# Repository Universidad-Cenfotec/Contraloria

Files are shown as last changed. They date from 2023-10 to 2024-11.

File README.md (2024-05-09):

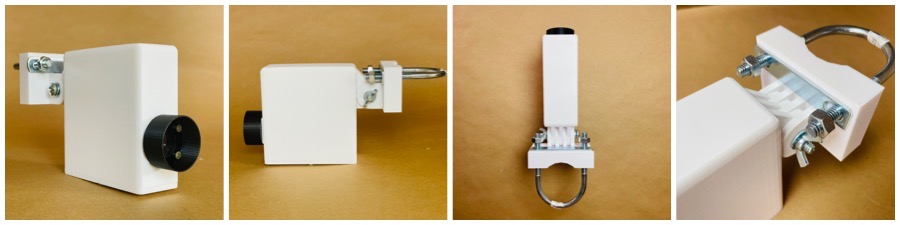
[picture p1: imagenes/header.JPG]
camara IoT

# Proyecto Fiscalización de Obra Pública IoT

Este es el resultado de un proyecto de investigación en coordinación con la Contraloría General de la República de Costa Rica y la cooperación alemana GIZ, para el desarrollo de cámaras IoT de bajo costo, que permitan monitorear y fiscalizar obras de construcción pública, incorporando ideas novedosas para el desarrollo de tecnología local y de bajo costo, además de la utilización de Inteligencia artificial para identificación de patrones de progreso de construcción pública. Este es el repositorio con todos los resultados del proyecto, y que permite su reproducción abierta.

El repositorio del piloto realizado por la contraloría se encuentra en este link:
https://github.com/cgrcostarica/fiscalizacion_infra_IA

## Organización del repositorio
- "code" códigos para los dispositivos utilizados. e instrucciones para programar el microcontrolador
- "design" Archivos 2D y 3D de diseño de estructuras de fabricación y soporte del sistema. Video instruccional de ensamblado de la cámara
- "documentos" Documentación de respaldo (presentaciones, reportes técnicos, documentos de soporte)
- "imagenes" conteien las imágenes que se utilizan en este repositorio
- "placa_tpl" detalles del diseño de la placa TPL, y los esquemas para fabricación

Estes es un proyecto realizado por **Universidad Cenfotec**, en cooperación con la Contraloría General de la República, con fondos de la GIZ.

Aunque exiten tecnologías en el mercado que podría cumplir esta función, este proyecto va dentro de la filosofía "Nuestros para fabricar, adaptar, reparar y crecer", es decir, la intencióne s crear tecnología sobre la cual se pueda evolucionar, y cuyo mejoramiento dependa de nuestras propias acciones y no de la capacidad de un proveedor.

## Investigadores Principales

Dr. Tomás de Camino Beck

Dr. Luis Carlos Naranjo

## Investigadores de apoyo

M.Sc. Rodrigo Herrera

# Asistentes de Investigación y Fabricación

Estudiante Jeffry Valverde

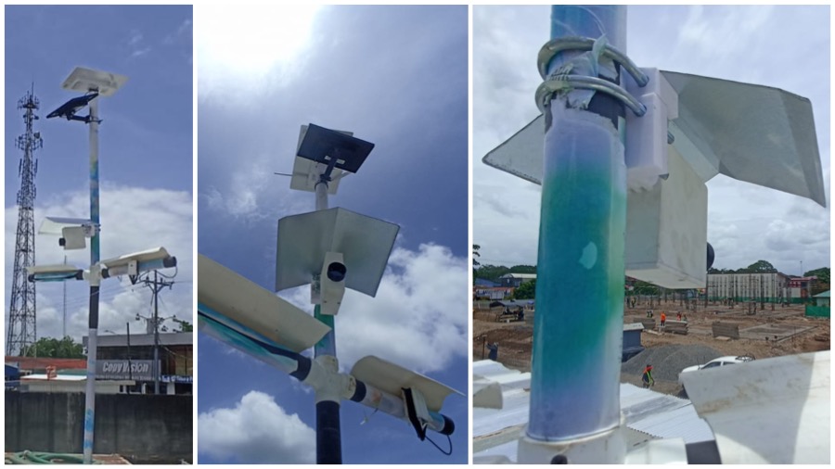
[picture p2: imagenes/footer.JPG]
Camaras Instaladas


# Etapa de Inteligencia Artificial

**Objetivo:** Crear un modelo de inteligencia artificial que permita realizar la detección de objetos en las imagenes captadas en la etapa de IOT relacionadas al proyecto de contrucción de la Escuela de Pocosi. 

## Investigadores Principales
M.Sc. Rodrigo Herrera

## Asistentes de Investigación y Desarrollo
Gabriel Lobo

Dr. Tomás de Camino Beck

La documentación necesaria de la etapa de IA se encuentra en la carpeta "Documentos Etapa IA-GIZ-CENFOTEC", dentro de la misma contiene la siguiente organización.
- "Códigos" :
  - Los archivos del docker que va en el proceso de producción *sin los modelos
  - El proceso de entrenamiento
  - Autenticación de Google Drive
- "Documentación"
  - La documentación necesaria para todos los procesos
- "Imagenes y Etiquetas
  - Etiquetas necesarias para llevar a cabo el proceso de entrenamiento y evaluación
  - Ejemplo de 5 imagenes
- "Modelos"
  - Contiene un txt que indica donde se puede encontrar los modelos
 
## Resultados de Modelos

Se han compartido 1 modelo principal. 
- Modelo_1_29
  - Metricas
    - Promedio de IoU: 82.7%
    - Sensitividad: 85.4% (Equivale a las predicciones verdaderamente predichas)

### Ejemplo de Inferencia 1
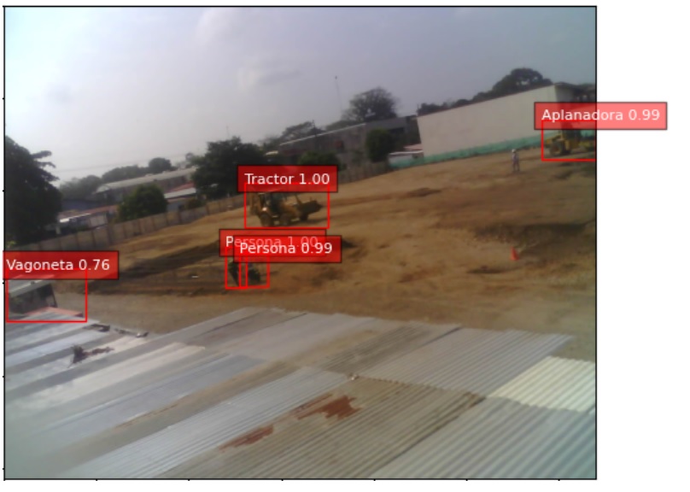
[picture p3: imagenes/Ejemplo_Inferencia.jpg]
Ejemplo de Inferencia
 

### Ejemplo de Inferencia 2
En este ejemplo se puede observar 2 cajas de diferente color en cada objeto. 

- La caja Azul es la caja de la etiqueta real

- La caja Roja es la caja de la predicción realizada por el modelo

Fácilemente se puede apreciar la efectividad del modelo en hacer su trabajo de predicción. 
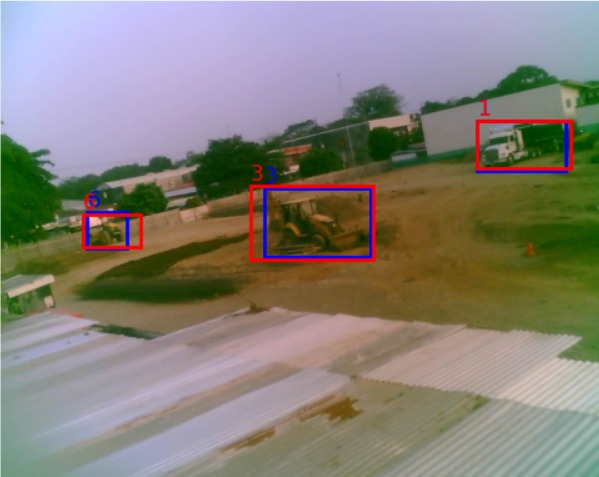
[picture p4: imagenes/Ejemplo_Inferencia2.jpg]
Ejemplo 2 de Inferencia


### Ejemplo de tabla de resultados
Parte del objetivo es analizar las imagenes que se obtengan por día y de estas obtener un archivo CSV en el cual permita analizar los resultados de una forma ágil y obtener resultados de analísis del monitoreo en las obras. 

En la siguiente imagen se observa un ejemplo del archivo CSV creado de las inferencias realizadas por el modelo, el mismo contiene 4 columnas
- Nombre de la Imagen = imagen analizada
- Clase = predicción de los objetos encontrados
- Probabilidad = probabilidad del objeto encontrado
- Recuadro = las coordenadas necesarias de donde se encontro el objeto en la imagen analizada

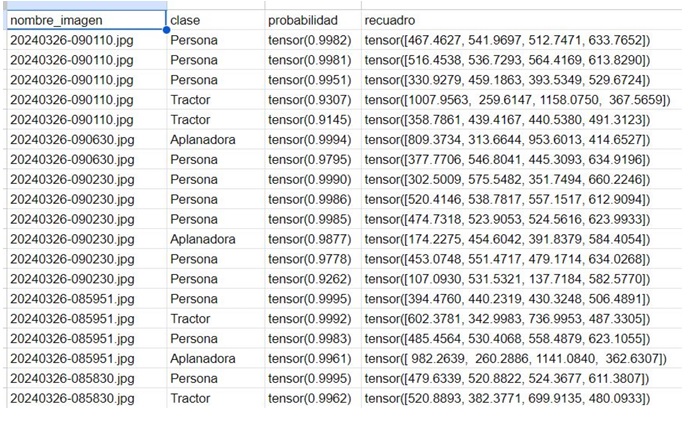
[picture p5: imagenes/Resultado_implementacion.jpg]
Tabla de Resultados


*Se debe tomar en cuenta que este modelo esta entrenado solamente con imagenes captadas por las camaras realizadas en la etapa de IoT para el proyecto de construcción de la Escuela de Pocosí, por ende este modelo esta sobre-entrenado para realizar inferencias para este proyecto, en caso de que se ponga el modelo a realizar inferencias de otras imagenes, o proyectos diferentes, es posible que el modelo no sea lo esperado en su eficiencia.

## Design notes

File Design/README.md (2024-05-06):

# Proceso de Diseño

- El proceso de diseño se explica en el [siguiente video](https://drive.google.com/file/d/1DGaU7ya0ZxTkijEyFO8wcMf-l3KS4jHS/view?usp=sharing)

# Archivos de Diseño

1. Caja_Camara_P1.stl  Caja que contiene la cámara
2. Caja_Camara_P2.stl  Tapa de la caja de cámara
3. Union_Camara_Poste.stl Pieza que sostiene la cámara al poste
4. Visor_Camara.stl Visor que proteje el elnte de lluvia y luz
5. Cubierta_Lente.svg  archivo para corte láser que ptotege el lente del ESP32CAM
6. Anclaje_Techo.stl Pieza que sostiene un techo de zinc al poste

# Recomendaciones para imprimir 3D

- Plástico: PLA MAX
- Pintura exterior esmalte blanco (protección rayos UV)
- Resolución: 0.2mm
- Capas y Paredes: forzar cuatro capas de paredes
- Relleno: 60% con patrón triangular para darle más resistencia
- La impresión tarda aproximadamente 9h25m en una Prusa MK4 en modo impresión rápida

--- 
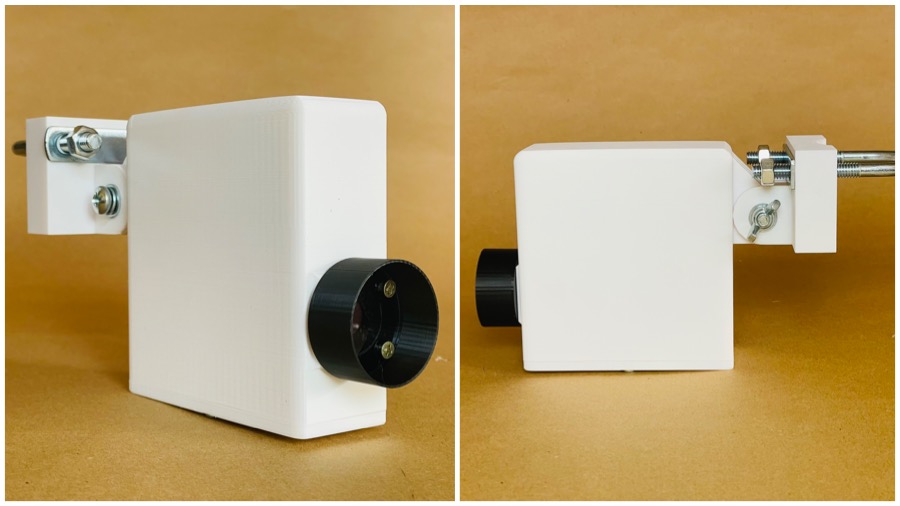
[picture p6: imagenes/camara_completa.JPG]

# Instrucciones de Armado de la Cámara

## Caja de la cámara
- Las instrucciones de armado de la cámara las ueden ver en el [siguiente video](https://drive.google.com/file/d/1R8fjxk--XU2Z1inmcDHXZ_iKdpq5K-TY/view?usp=sharing)
## Incorporar el ESP32 a la caja
- Cambiar el WiFi y direcciónd e Google Drive, siguiendo estas instrucciones
- El ESP32, se conecta a la placa TPL5110, a través de el adaptador de plástico como se muestra en la siguientes fotos
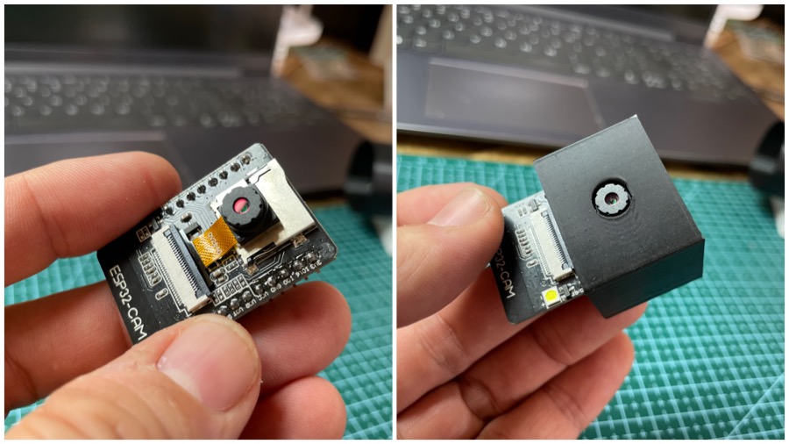
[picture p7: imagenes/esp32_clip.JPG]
ESP32 Clip
  
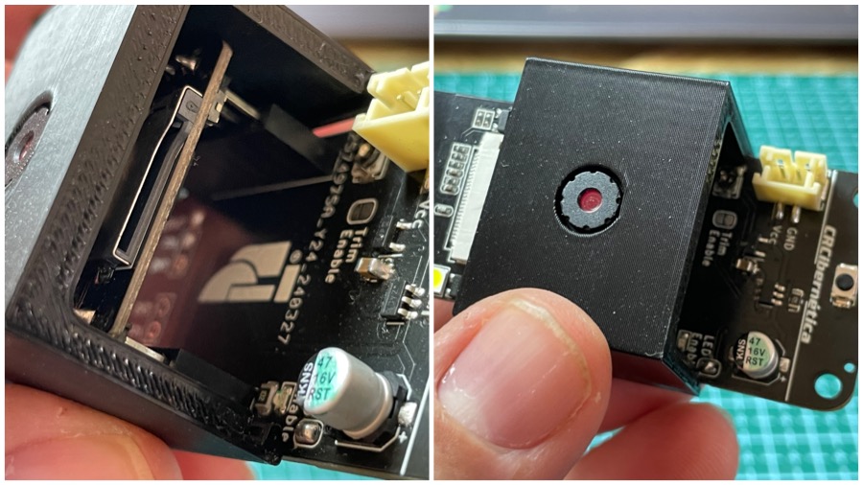
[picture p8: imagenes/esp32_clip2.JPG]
  
- Una vez conectado el ESP32 a la placa, se conectan las baterías, seinserta en la cámara, con cuidado, como se muestra en las siguientes fotografías
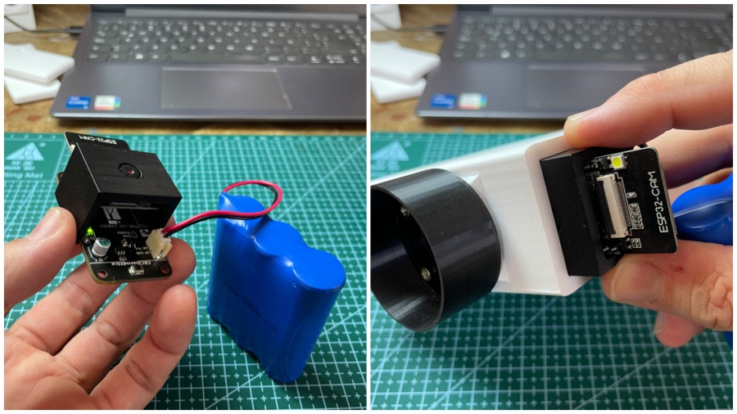
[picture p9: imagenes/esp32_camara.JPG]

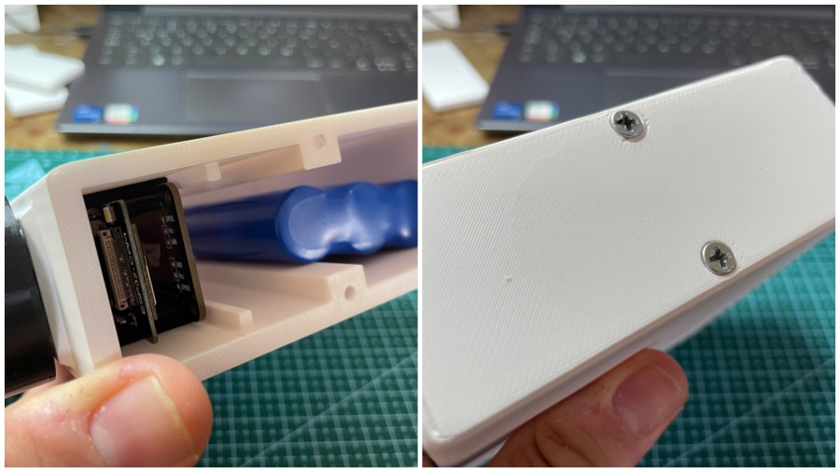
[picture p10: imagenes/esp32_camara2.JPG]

- Una vez cerrada la cámara probar que suba las fotos.

## Modificación de los intervalos de fotografía
- Para modificar en intervalo en que el ESP32 toma las fotos, seguir las instrucciones de este video.

## Cargado de baterías

- Para el cargado de baterías seguir las instrucciones del siguiente video

---
# Historial de Diseño

## Versión 1

Problemas:
- Tapa difícil de colocar
- Cavidad permite pocos tipos de batería
- Se necesita dar vuelta a la imágen
- "Lente" difícil de instalar, y no se puede reparar.
- No resiste golpes muy fuertes

## Versión 2

Problemas:
- Lente expuesto se moja fácilmente
- Acrílico genera reflejos que hace que la foto se sobre exponga
- Union a anclaje hace que cámara quede muy separada del techo

Todo estos problemas han sido corregidos en la verisón final publicada

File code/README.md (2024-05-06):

# Códigos proyecto contraloría

El código ESP32CAM_Timer_CGR_Day.ino proporcionado realiza varias operaciones con un módulo de cámara ESP32CAM, culminando en el envío de una imagen a Google Drive. Una característica notable es el uso de `digitalWrite(donepin, HIGH)`, que se emplea para indicar la finalización de un proceso, activando un temporizador que apaga el controlador. A continuación, se detalla cómo se integra esta función dentro del flujo de trabajo del código:

1. **Establecimiento de la conexión WiFi**:
   - El ESP32 intenta conectarse a la red WiFi especificada. Si no logra conectarse dentro de un número máximo de intentos (`MAX_TRIES`), se considera que ha fallado.
   - Al fallar, ejecuta `digitalWrite(donepin, HIGH)` para indicar que el proceso ha terminado y activa un temporizador externo, que eventualmente apaga el controlador.

2. **Sincronización de tiempo y verificación de horario**:
   - Después de establecer la conexión WiFi, el ESP32 sincroniza su reloj con un servidor NTP.
   - Verifica si la hora actual está fuera del rango establecido (antes de las 5 a.m. o después de las 6 p.m.). Si es así, se activa el temporizador externo mediante `digitalWrite(donepin, HIGH)` para apagar el dispositivo.

3. **Inicialización y configuración de la cámara**:
   - Se configura y activa la cámara. Si la inicialización falla, el sistema se reinicia.
   - Al finalizar la captura y el envío de la imagen, se activa nuevamente el temporizador externo con `digitalWrite(donepin, HIGH)`, indicando que el proceso ha concluido.

4. **Función `saveCapturedImage()`**:
   - Realiza la captura de la imagen, la codificación en base64 y la envía a Google Drive.
   - Tras enviar la imagen, se activa el temporizador externo con `digitalWrite(donepin, HIGH)` para indicar el fin del proceso.

5. **Apagado del sistema**:
   - Cada vez que se llama a `digitalWrite(donepin, HIGH)`, se señala a un circuito externo (probablemente un temporizador o un controlador de potencia) para que inicie el proceso de apagado del ESP32.
  
¡Claro! Aquí tienes un conjunto básico de instrucciones para programar un ESP32-CAM utilizando el Arduino IDE:

---
# Programando el ESP32-CAM

- Para una explicación completa de como cargar el código a el ESP32-CAM, utilizando el Arduino IDE, lo encontrarán en [este video](https://drive.google.com/file/d/1rJqG5vgmPwFNBq3uttZ2uOI0OXYprOTJ/view?usp=sharing).

---
# Cambio de SSID y Password para red MiFi/WiFi

Para cambiar el acceso WiFi en el código proporcionado, sigue estos pasos:

1. **Abre el Código en el Arduino IDE:**
   - Abre el Arduino IDE en tu ordenador.
   - Copia y pega el código proporcionado en este GitHub en una nueva ventana del Arduino IDE.

2. **Edita la Información de la Red:**
   - Reemplaza el SSID y la contraseña con los de tu red WiFi. Por ejemplo:

   ```cpp
   const char* ssid = "nombre_de_tu_red_wifi";
   const char* password = "tu_contraseña_wifi";
   ```

5. **Guarda y Carga el Código:**
   - Guarda los cambios en el código.
   - Conecta tu ESP32-CAM al ordenador.
   - Selecciona el puerto adecuado y la placa ESP32-CAM en el Arduino IDE.
   - Haz clic en el botón "Upload" para cargar el código modificado en tu ESP32-CAM.

---

# Crear acceso para subir fotos a Google Drive

### 1. Crear el Acceso a Google Drive:

#### 1.1. Crear una Carpeta en Google Drive:
   - Abre Google Drive en tu navegador web.
   - Crea una nueva carpeta donde se guardarán las imágenes que envíe tu ESP32-CAM.

#### 1.2. Obtener el ID de la Carpeta:
   - Haz clic derecho en la carpeta que acabas de crear y selecciona "Obtener enlace".
   - Copia el ID de la carpeta de la URL. El ID de la carpeta es la parte de la URL después de `/folders/`.

#### 1.3. Crear un Nuevo Proyecto en Google Apps Script:
   - Visita el [Editor de Google Apps Script](https://script.google.com/) y crea un nuevo proyecto.

#### 1.4. Escribir el Script en Google Apps Script:
   - En el editor de scripts, copia y pega el siguiente código JavaScript:

   ```javascript
   function doPost(e) {
     var folderId = "ID_de_tu_Carpeta_en_Google_Drive";
     var folder = DriveApp.getFolderById(folderId);
     var blob = e.postData.getBlob();
     var file = folder.createFile(blob);
     return ContentService.createTextOutput("Archivo guardado: " + file.getName());
   }
   ```

   - Reemplaza `"ID_de_tu_Carpeta_en_Google_Drive"` con el ID de la carpeta que obtuviste anteriormente.

#### 1.5. Publicar el Script:
   - Haz clic en `Editar` y selecciona `Desplegar como web app`.
   - En la ventana emergente, elige `Quien tiene acceso a la aplicación: Cualquier persona, incluso anónimos`.
   - Haz clic en `Desplegar` y luego en `OK`.
   - Copia el URL que se genera, lo necesitarás más adelante.

### 2. Modificar el Código para tener Acceso:

#### 2.1. Configurar los Datos de Red WiFi:
   - Abre el código en C/C++ de tu ESP32-CAM.
   - Busca la sección "Datos de Red" y cambia los valores de `ssid` y `password` con los de tu red WiFi:

   ```cpp
   //******* Datos de Red ******
   const char* ssid = "nombre_de_tu_red_wifi";       // El SSID de tu red
   const char* password = "tu_contraseña_wifi";  // Tu contraseña de red
   // ***************************
   ```

   - Sustituye `"nombre_de_tu_red_wifi"` y `"tu_contraseña_wifi"` por el nombre de tu red WiFi y tu contraseña respectivamente.

#### 2.2. Configurar el Script de Google Apps Script:
   - Busca la sección donde se define `myDomain` y `myScript`.
   - Reemplaza `myScript` con el URL del script de Google Apps Script que generaste anteriormente.

   ```cpp
   const char* myDomain = "script.google.com";
   String myScript = "/macros/s/TU_ID_EXEC";    // Reemplaza con tu propio URL
   ```

   - Reemplaza `"TU_ID_EXEC"` con el ID de ejecución que obtuviste del URL del script.

--- 

# Ajuste de los intervalos de tiempo

- Los intervalos en los que se toman la fotografías se ajustan físicamente en la placa TPL, regulando el peqieño potenciómetro de la placa TPL, como se muestra en la siguiente foto.
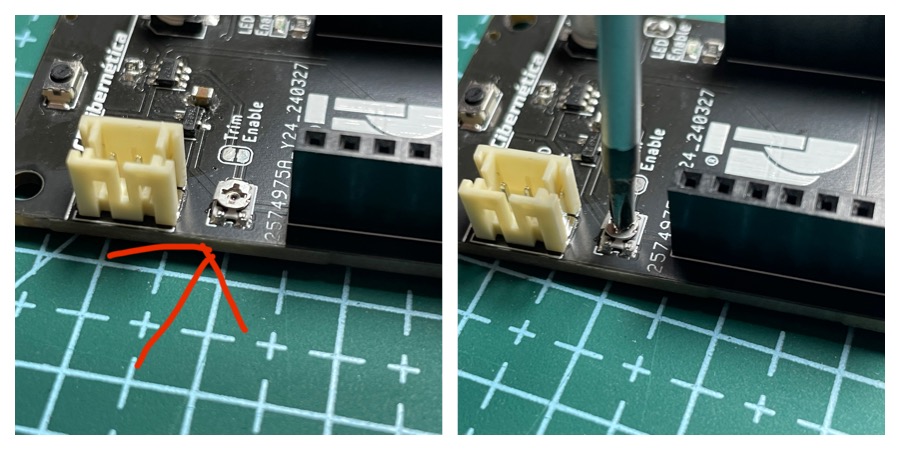
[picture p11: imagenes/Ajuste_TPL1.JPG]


- Cuando el potenciómetro está completamente a la izquierda el intervalo de tiempo es de aproximadamente 2 horas, mientras que cuando está completamente a la derecha, el intervalo es de menos de 1 minuto.  Para efectos del proyecto (intervalo de 10 min), se cooca el potenciómetri alrededor de la 1 del reloj, como se ven en la siguiente foto.

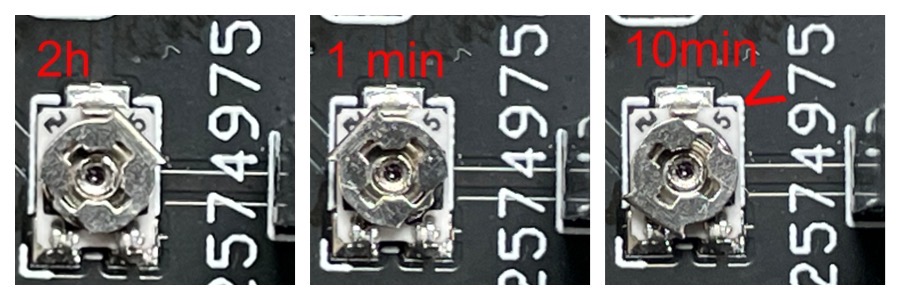
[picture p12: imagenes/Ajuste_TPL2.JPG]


---

# Instrucciones generales de programación de Placa ESP32-CAM

1. **Instalar el Arduino IDE:**
   - Descarga e instala la última versión del Arduino IDE desde el sitio web oficial: https://www.arduino.cc/en/software.

2. **Instalar el Soporte para ESP32 en el Arduino IDE:**
   - Abre el Arduino IDE.
   - Ve a `File (Archivo) > Preferences (Preferencias)`.
   - En el campo "Additional Board Manager URLs (URLs Adicionales del Gestor de Placas)", añade la siguiente URL: `https://dl.espressif.com/dl/package_esp32_index.json`.
   - Haz clic en "OK".
   - Ve a `Tools (Herramientas) > Board (Placa) > Boards Manager (Gestor de Placas)`.
   - Busca "esp32" y pulsa en "Install (Instalar)" para instalar el soporte para ESP32.

3. **Seleccionar la Placa ESP32-CAM:**
   - Ve a `Tools (Herramientas) > Board (Placa)` y selecciona `ESP32 Wrover Module`.

4. **Configurar las Opciones de la Placa:**
   - Ve a `Tools (Herramientas)` y ajusta las siguientes opciones según sea necesario:
     - `Upload Speed (Velocidad de Subida)`: 115200 baudios (o la velocidad de subida que mejor funcione para tu configuración).
     - `Flash Frequency (Frecuencia de Flash)`: 40 MHz.
     - `Flash Mode (Modo de Flash)`: QIO.
     - `Partition Scheme (Esquema de Partición)`: Huge APP (3MB No OTA/1MB SPIFFS).

5. **Conectar el ESP32-CAM a tu Ordenador:**
   - Conecta tu ESP32-CAM al ordenador utilizando un cable micro-USB.

6. **Configurar el Arduino IDE para la Comunicación con el ESP32-CAM:**
   - Si es la primera vez que utilizas el ESP32-CAM con tu ordenador, es posible que necesites instalar los controladores correspondientes. En la mayoría de los casos, el sistema operativo los instalará automáticamente, pero si experimentas problemas de comunicación, puedes buscar los controladores en línea.

7. **Cargar un Ejemplo o Escribir Tu Propio Código:**
   - Ve a `File (Archivo) > Examples (Ejemplos)` y selecciona un ejemplo para comenzar, como `CameraWebServer` o `CameraWebServer.ino`.
   - O bien, escribe tu propio código en el Arduino IDE.

8. **Modificar el Código (si es necesario):**
   - Si estás utilizando un ejemplo, puedes necesitar modificar ciertas partes del código, como la configuración del Wi-Fi (SSID y contraseña) para que coincida con tu red Wi-Fi.

9. **Compilar y Subir el Código:**
   - Haz clic en el botón "Upload (Subir)" en la esquina superior izquierda del Arduino IDE.
   - Espera a que el código se compile y se suba al ESP32-CAM.

10. **Verificar la Ejecución:**
    - Una vez que la carga haya finalizado correctamente, abre el Monitor Serie (`Tools (Herramientas) > Serial Monitor (Monitor Serie)`) para ver la salida del ESP32-CAM.
    - Si has cargado un ejemplo de cámara web, deberías poder acceder a la dirección IP del ESP32-CAM desde un navegador web y ver la transmisión de la cámara.

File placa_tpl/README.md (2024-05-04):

# Placa TPL para ESP32CAM

Shield para cámara ESP32CAM, con chip TPL para fotos a intervalos y bajo consumo de batería. Diseñado por Tomás de Camino Beck, con ayuda de CrCibernetica.com, para poryecto GIZ-CGR-Universidad Cenfotec.

Para actualizciones de esta placa puede revisar [este repositorio](https://github.com/CRCibernetica/cnft-tpl-esp32cam)

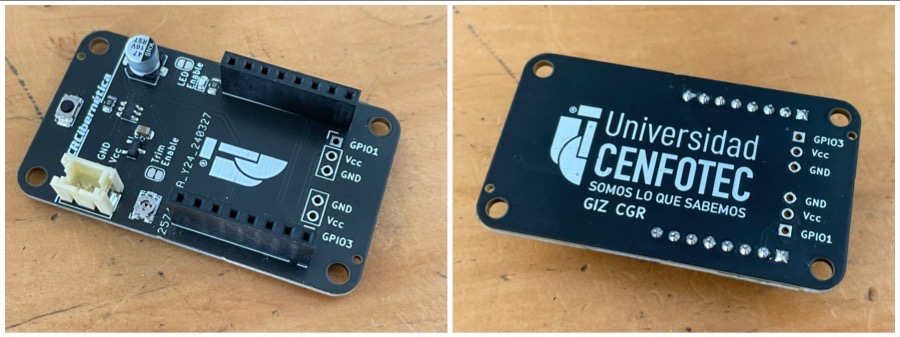
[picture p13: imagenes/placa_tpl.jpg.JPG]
Placa TPL


# Prototipado de la placa

La placa se desarrolla a partir del chip TPL5110.  En la fotografía se muestra 1. Pruebas breadboard, 2. fabricado protoboard, 3. placa final fabricada en china

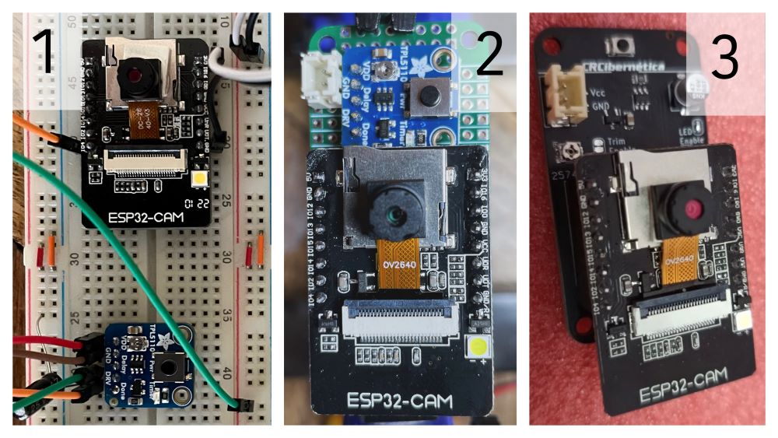
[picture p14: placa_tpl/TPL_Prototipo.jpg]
prototipado


# Breadboard

Utilizando el TPL5110 de Adafruir puede construir el circuito en un breadboard siguiendo el siguiente esquema:
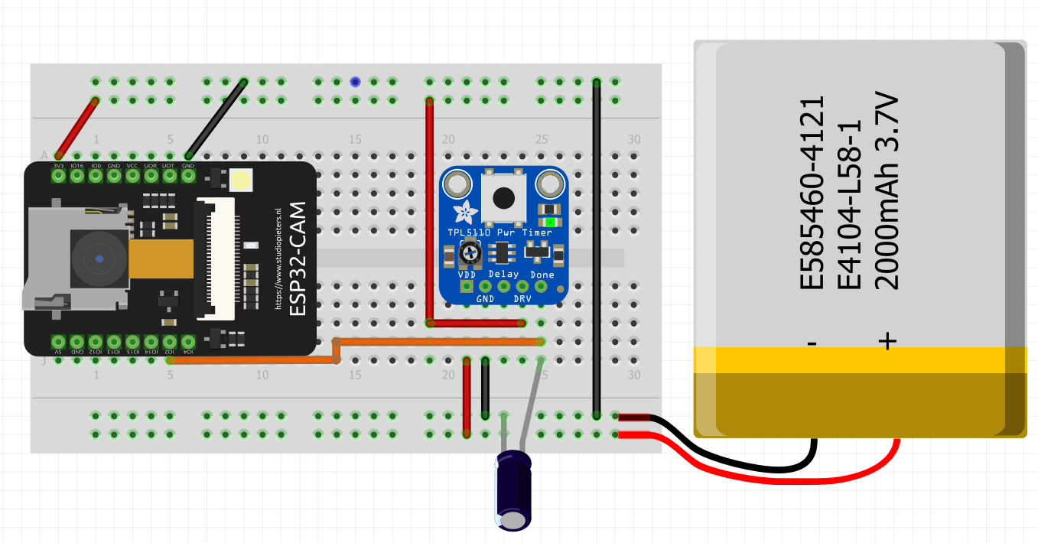
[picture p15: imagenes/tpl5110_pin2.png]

Nota: El capacitor puede variar depediendo de la batería que se utilice. Para este proyecto se utilizó 47uF 16v

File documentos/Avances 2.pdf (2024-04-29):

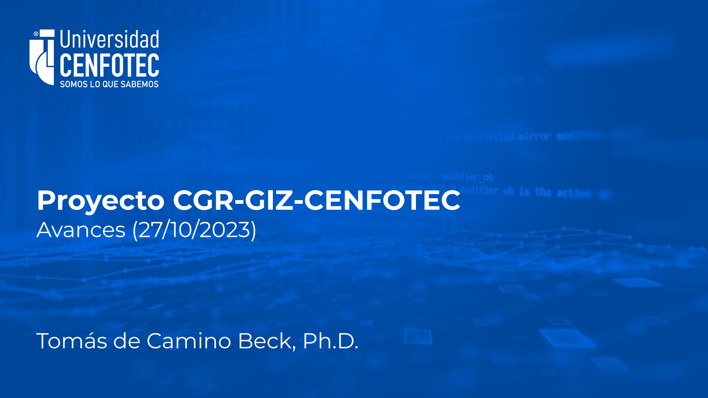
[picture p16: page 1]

Tomás de Camino Beck, Ph.D.

# Proyecto CGR-GIZ-CENFOTEC

# Avances (27/10/2023)

# CGR-GIZ-CENFOTEC

# Energía

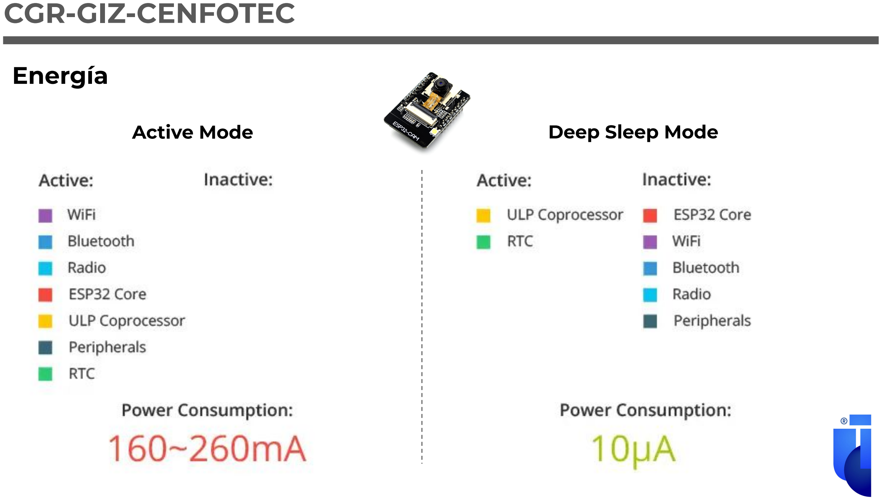
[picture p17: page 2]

Active Mode | Deep Sleep Mode

# CGR-GIZ-CENFOTEC

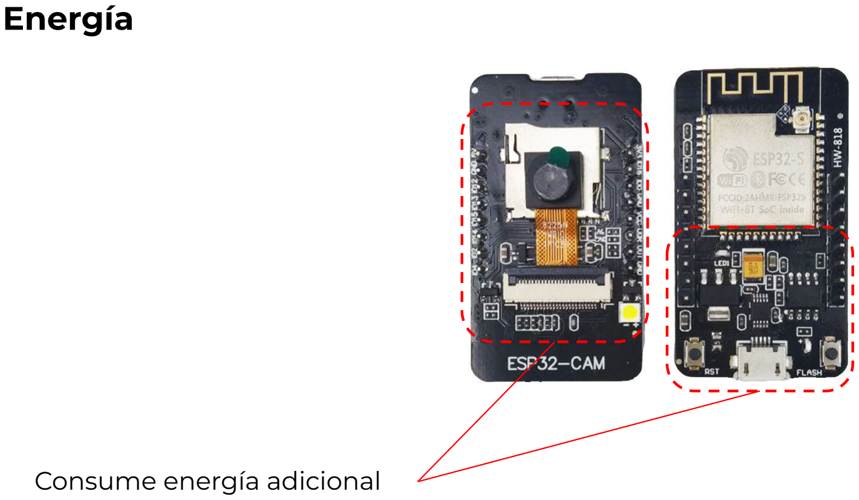
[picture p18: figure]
Energía; Consume energía adicional

# CGR-GIZ-CENFOTEC

# Energía

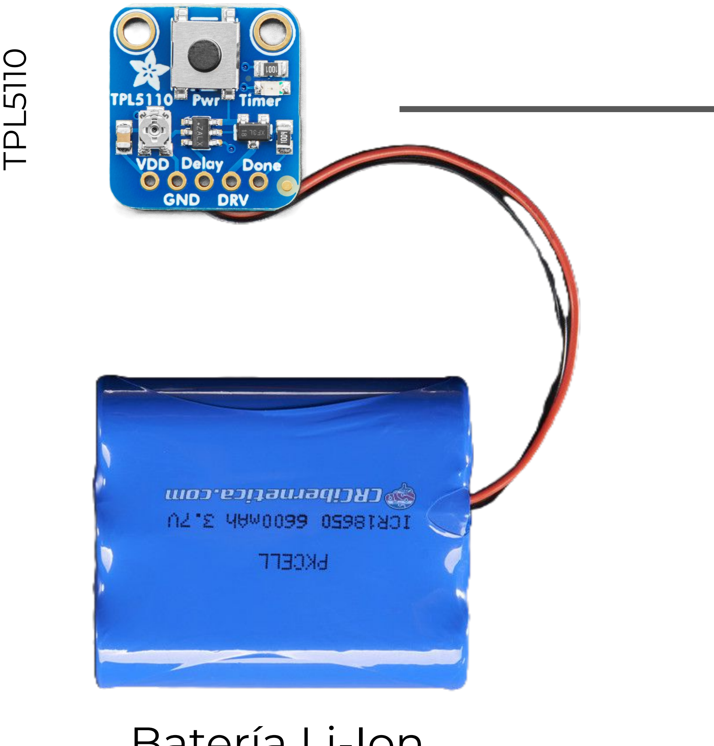
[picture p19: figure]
TPL5110

# Batería Li-Ion

3.7 V

## 66000mAh

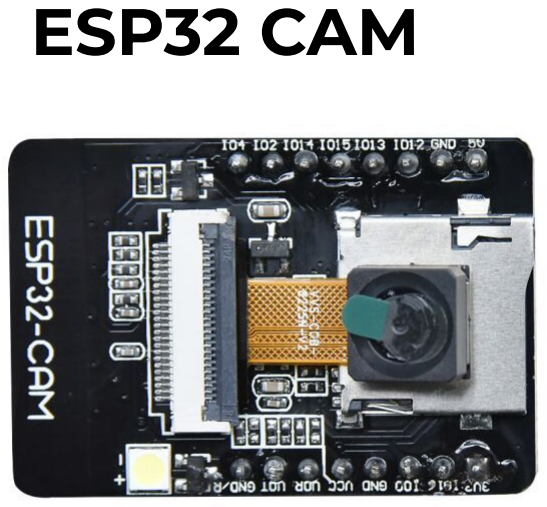
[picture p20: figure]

# ESP32 CAM Timer (externo)

# CGR-GIZ-CENFOTEC

# Energía

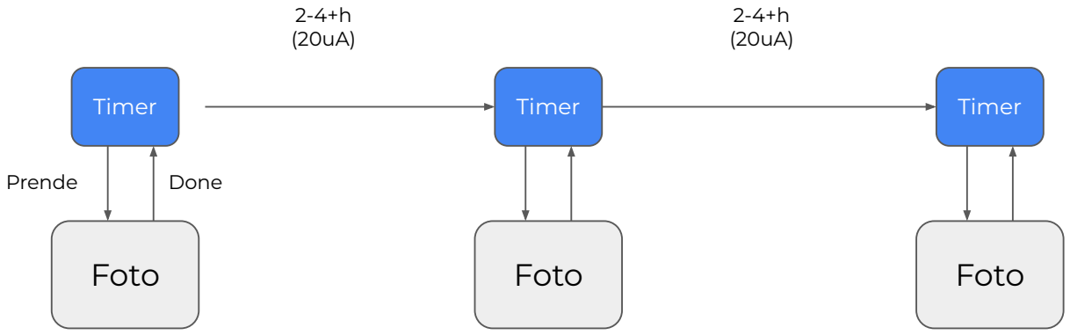
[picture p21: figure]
Foto; Timer; Prende; Done

5-10 s
(260mA)

5-10 s
(260mA)

5-10 s
(260mA)

# CGR-GIZ-CENFOTEC

# Ventajas - Simplifica el diseño - No requiere paneles solares - Dura más de 1 año con batería - Facilita protección a exteriores - Minimiza consumo energía - Garantiza lectura regular - Maximiza vida útil del controlador

# CGR-GIZ-CENFOTEC

# Caja

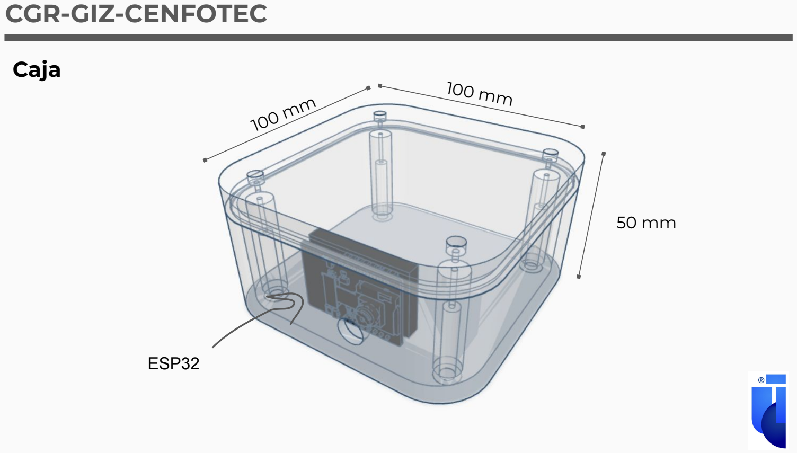
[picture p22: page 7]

# ESP32

50 mm

100 mm
100 mm

# CGR-GIZ-CENFOTEC

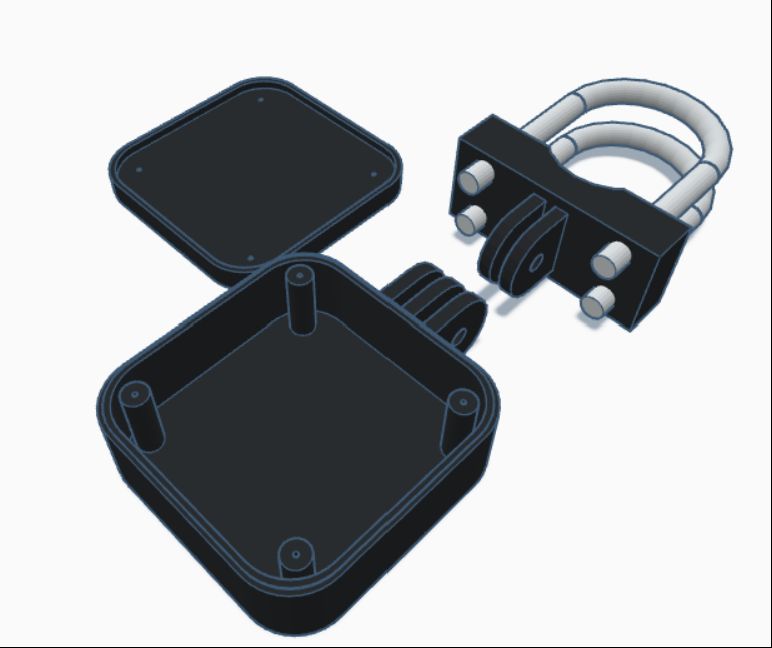
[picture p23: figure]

# Soporte

# CGR-GIZ-CENFOTEC

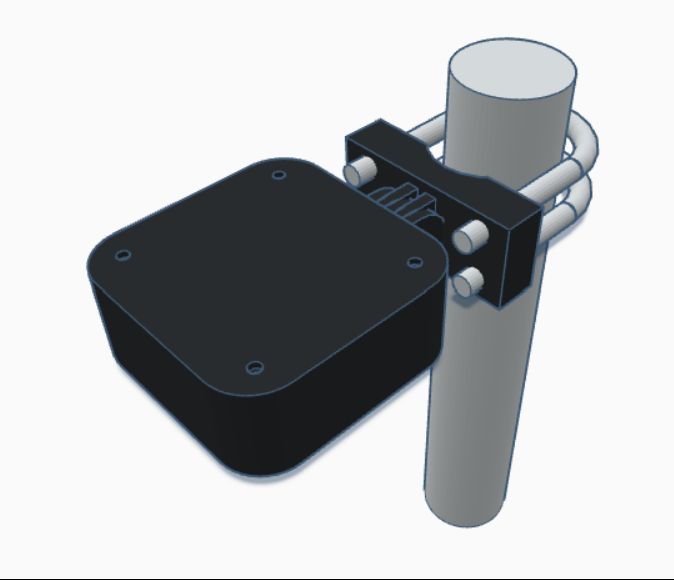
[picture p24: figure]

# Soporte

# CGR-GIZ-CENFOTEC

# Soporte

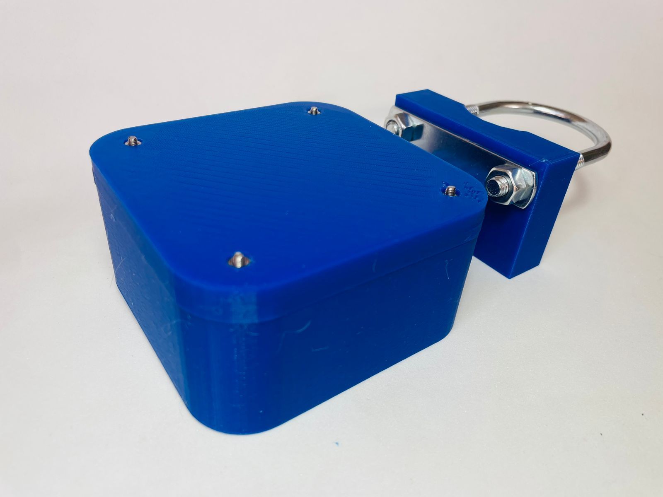
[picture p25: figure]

# CGR-GIZ-CENFOTEC

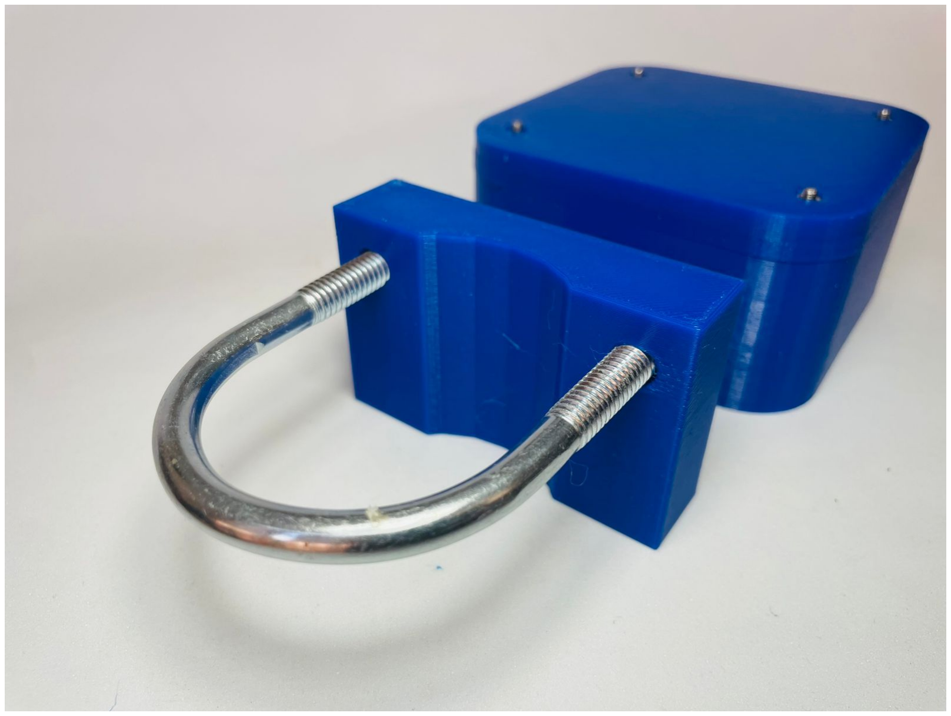
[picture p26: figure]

# Soporte

# CGR-GIZ-CENFOTEC

# Soporte

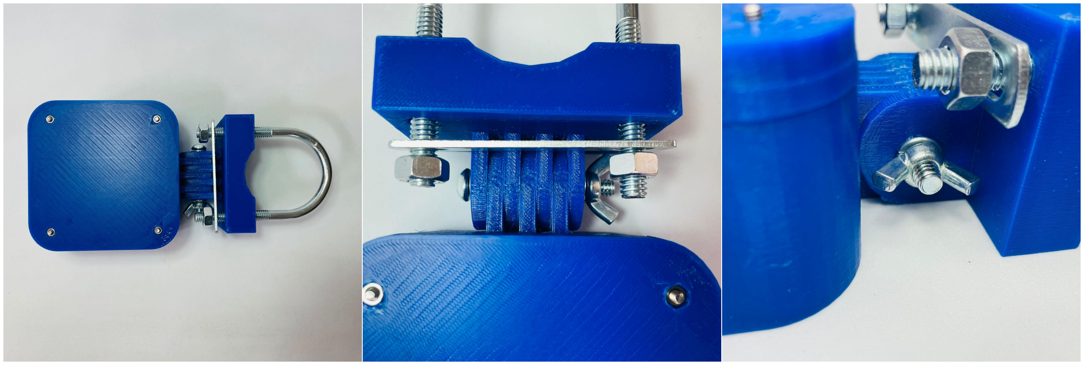
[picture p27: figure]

# CGR-GIZ-CENFOTEC

# Soporte

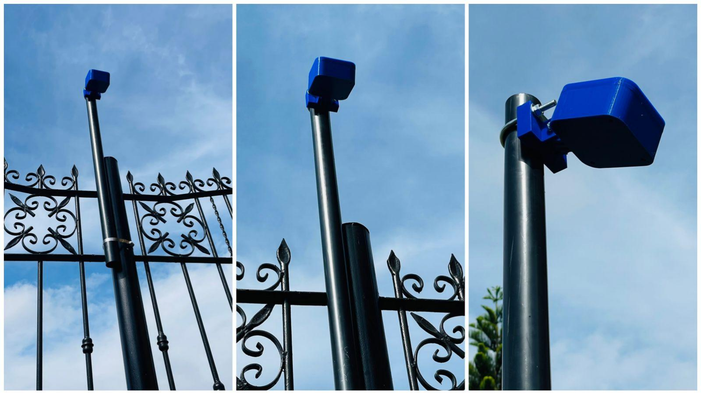
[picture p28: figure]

# CGR-GIZ-CENFOTEC

Item | Descripción | Resultados Preliminares | Estado
Pruebas de microcontroladores | Pruebas de diferentes microcontroladores | Se probaron Arduino Nicla, T-Camera, ESP32 CAM, Se determina que ESP32 es la mejor opción | Listo
| | evitar su uso | Listo
| Baterías | Li-Ion 6600mAh, LiPo 5500mAh, LiPo 2500mAh, CR123 Li | Listo
| Estados de baja energía | Deep Sleep, Aumenta duración de batería. PLacas traen muchos componentes que gastan energía, PLaca en prueba (lleva 1 semana) | Listo
| Timer | En Proceso | En Proceso
Pruebas de Energía | Paneles solares | Se probó voltaic, no se descarta, pero se trata de
Caja | Diseño | DIseño simple | Listo
Impresión 3D | Diseño trabajable en Tinkedcad | Listo
Materiales | ASA, PLA | Listo
Resistencia | Pruebas en exterior en Proceso | En Proceso

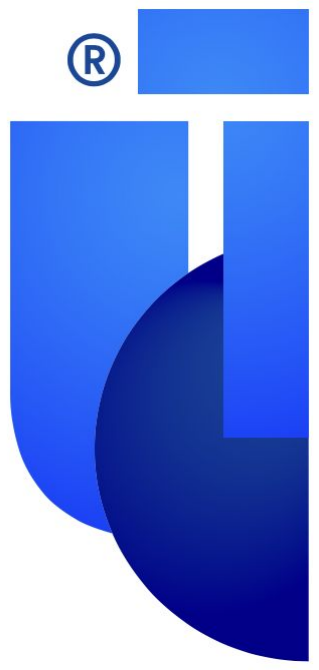
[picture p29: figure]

# @tomasdecamino

# tdecamino@ucenfotec.ac.cr

# ¿Preguntas?

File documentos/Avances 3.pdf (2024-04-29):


Tomás de Camino Beck, Ph.D.

## Proyecto CGR-GIZ-CENFOTEC

Avances (23/11/2023)

Concepto; Internet; Soporte; Cámara; Caja; Energía

CGR-GIZ-CENFOTEC

CGR-GIZ-CENFOTEC

Principios de Diseño

- Duradero (no eterno)
- Bajo Costo
- Reparable
- Replicable
- Modificable
- Energéticamente independiente (evitar paneles solares)
- Fácil de instalar
- Código y diseños abiertos (Open Source)


CGR-GIZ-CENFOTEC

Soporte

CGR-GIZ-CENFOTEC


Soporte

CGR-GIZ-CENFOTEC

Soporte


CGR-GIZ-CENFOTEC


Soporte

CGR-GIZ-CENFOTEC


Circuito

CGR-GIZ-CENFOTEC


Circuito

CGR-GIZ-CENFOTEC


Circuito

CGR-GIZ-CENFOTEC

Circuito


CGR-GIZ-CENFOTEC


Ensamblado


CGR-GIZ-CENFOTEC

Ensamblado

CGR-GIZ-CENFOTEC

Ensamblado


CGR-GIZ-CENFOTEC

Funcionamiento

Fotografía; (reconocimiento patrones); Decisión; Juicio

CGR-GIZ-CENFOTEC


IA


@tomasdecamino

tdecamino@ucenfotec.ac.cr

# ¿Preguntas?

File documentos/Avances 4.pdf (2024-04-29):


Tomás de Camino Beck, Ph.D.

## Proyecto CGR-GIZ-CENFOTEC

Avances (8/03/2024)

CGR-GIZ-CENFOTEC


CGR-GIZ-CENFOTEC

Versión 1 | Versión 2

CGR-GIZ-CENFOTEC


CGR-GIZ-CENFOTEC


CGR-GIZ-CENFOTEC


CGR-GIZ-CENFOTEC


CGR-GIZ-CENFOTEC

Circuito

Pruebas con pin 4,2,16 Pruebas con Capacitores

Pruebas SD

Pruebas
Baterías


CGR-GIZ-CENFOTEC

CGR-GIZ-CENFOTEC


CGR-GIZ-CENFOTEC


CGR-GIZ-CENFOTEC


CGR-GIZ-CENFOTEC

Importante

- Revisión de electrónica
- Diseño de placa (CrCibernetica)
- Pruebas de caja (se rediseño)
- Diseño de techo
- Fabricación de cámara (12h)
- Cambio de batería
- Algunos asuntos del código
- DIstancia de sitio de prueba (Pococí está muy largo)
- Semana Santa


@tomasdecamino

tdecamino@ucenfotec.ac.cr

# ¿Preguntas?

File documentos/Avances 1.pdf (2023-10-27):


Tomás de Camino Beck, Ph.D.

# Proyecto CGR-GIZ-CENFOTEC

# Avances (27/10/2023)

# CGR-GIZ-CENFOTEC

# Concepto

Internet; Soporte; Cámara; Caja; Energía

# CGR-GIZ-CENFOTEC

# Supuestos

# (iniciales)

# - Internet: Hay disponibilidad de Wi-Fi. Inicialmente al ser obras MEP, se asume que es posible (MiFi)

# - Energía: Sistema autónomo con energía solar

# - Soporte: Construcción con containers o estructuras de bodega o cercado

# - Cámara: hay visibilidad (fase de preparación de terreno y preparación de fundamentos)

# - Caja: resiste intemperie al menos 1 año

# CGR-GIZ-CENFOTEC

# Internet


# CGR-GIZ-CENFOTEC

# Cámara


ESP32 CAM | NIcla Vision | T-Camera
micro ESP32 soporta IA local | micros soportan IA local | micro ESP32 soporta IA local
Gran cantidad de material en línea | Poca cantidad de material en línea | Gran cantidad de material en línea
$15 | $115 | $50
Cámara 2MP | Cámara 2MP, micrófono, acelerómetro | Cámara 5MP, sensor PIR, pantalla
Modo bajo consumo | ND | Modo bajo consumo
Escalable | ? | ?

# CGR-GIZ-CENFOTEC

# Energía


Active Mode | Deep Sleep Mode

# CGR-GIZ-CENFOTEC

frecuencia de funcionamiento ● Nos interesa que dure meses o semanas ● Carga continua con panel solar; Panel Solar; Super Capacitor; Manejo de Carga; Batería LiPo; ESP32 CAM

Energía | ● | ESP32 puede durar años funcionando, dependiendo de

# Caja

# CGR-GIZ-CENFOTEC


$29

# CGR-GIZ-CENFOTEC

# Caja


### ESP32

50 mm

100 mm
100 mm


# Caja

# CGR-GIZ-CENFOTEC

# Caja

# CGR-GIZ-CENFOTEC


# Sistema

# CGR-GIZ-CENFOTEC


# CGR-GIZ-CENFOTEC

# Sistema


# CGR-GIZ-CENFOTEC

# Sistema


# CGR-GIZ-CENFOTEC


# Soporte

# CGR-GIZ-CENFOTEC


# Soporte

# CGR-GIZ-CENFOTEC

# Soporte



## @tomasdecamino

# tdecamino@ucenfotec.ac.cr

# ¿Preguntas?

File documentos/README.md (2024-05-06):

# Documentación Adicional

- Presetaciones de avance realizadas durante el desarrollo del proyecto.

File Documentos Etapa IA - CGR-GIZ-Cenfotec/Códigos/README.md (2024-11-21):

El modelo completo puede ser sercargao en el siguiente [link](https://drive.google.com/drive/folders/1GQ3o4Iqyp_PoVP5M7APWEdD5sbGEHZOf)

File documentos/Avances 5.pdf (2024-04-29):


Tomás de Camino Beck, Ph.D.

## Proyecto CGR-GIZ-CENFOTEC

Avances (15/03/2024)

CGR-GIZ-CENFOTEC


CGR-GIZ-CENFOTEC


CGR-GIZ-CENFOTEC


CGR-GIZ-CENFOTEC


CGR-GIZ-CENFOTEC

CGR-GIZ-CENFOTEC

CGR-GIZ-CENFOTEC


CGR-GIZ-CENFOTEC


CGR-GIZ-CENFOTEC


CGR-GIZ-CENFOTEC

CGR-GIZ-CENFOTEC


CGR-GIZ-CENFOTEC


CGR-GIZ-CENFOTEC

Importante

- Revisión de electrónica
- Diseño de placa (CrCibernetica)
- Pruebas de caja (se rediseño)
- Diseño de techo
- Fabricación de cámara (12h)
- Cambio de batería
- Algunos asuntos del código

7.5h


@tomasdecamino

tdecamino@ucenfotec.ac.cr

# ¿Preguntas?

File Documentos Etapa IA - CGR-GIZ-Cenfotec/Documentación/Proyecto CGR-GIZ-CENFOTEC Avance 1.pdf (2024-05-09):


# Proyecto CGR-GIZ-CENFOTEC

## IA – Modelo y Estimación de implementación

Msc. Rodrigo Herrera

# CGR-GIZ-CENFOTEC

## Objetivo

## - Avances del Modelo - Demo - Revisión de arquitectura de implementación - Revisión de costos de arquitectura


Imágenes | Vagonetas

Excavadoras


Imágenes
Cargadores

Personas

Imágenes


Cantidad por clase son:

- Dump_truck: 7855
- Excavator: 7323
- Loader: 4870
- Mixer_truck: 1992
- Person: 2192

Mezcladoras


Modelos

Modelo



Modelo


Demo


Arquitectura de implementación

Nuevas Imágenes

Imágenes procesadas

Archivos


Estimación de Costos

# Proyecto CGR-GIZ-CENFOTEC

## IA – Modelo y Estimación de implementación

Msc. Rodrigo Herrera

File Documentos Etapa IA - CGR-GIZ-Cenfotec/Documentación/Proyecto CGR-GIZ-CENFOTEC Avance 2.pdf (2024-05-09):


# Proyecto CGR-GIZ-CENFOTEC

## IA – Modelo y Estimación de implementación

Msc. Rodrigo Herrera

# CGR-GIZ-CENFOTEC

## Objetivo

## - Avances del Modelo - Demo - Revisión de arquitectura de implementación - Revisión de costos de arquitectura


Imágenes | Vagonetas

Excavadoras


Imágenes
Cargadores

Personas

Imágenes


Cantidad por clase son:

- Dump_truck: 7855
- Excavator: 7323
- Loader: 4870
- Mixer_truck: 1992
- Person: 2192

Mezcladoras

Modelos y proceso de entrenamiento



Demo


Arquitectura de implementación

Nuevas Imágenes

Imágenes procesadas


Archivos


Estimación de Costos

# Proyecto CGR-GIZ-CENFOTEC

## IA – Modelo y Estimación de implementación

Msc. Rodrigo Herrera

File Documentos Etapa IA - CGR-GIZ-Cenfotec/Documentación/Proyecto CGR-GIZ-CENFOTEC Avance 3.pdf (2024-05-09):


# Proyecto CGR-GIZ-CENFOTEC

## IA – Modelo y Estimación de implementación

Msc. Rodrigo Herrera

# CGR-GIZ-CENFOTEC

## Objetivo

## - Avances del Modelo - Demo - Revisión de arquitectura de implementación - Revisión de costos de arquitectura


Imágenes | Vagonetas

Excavadoras


Imágenes
Cargadores

Personas

Imágenes


Cantidad por clase son:

- Dump_truck: 7855
- Excavator: 7323
- Loader: 4870
- Mixer_truck: 1992
- Person: 2192

Mezcladoras

Modelos y proceso de entrenamiento


Demo

https://colab.research.google.com/drive/1PjbNF5KaKsJHKqpBVtwylxMjkuDdpaJe?authuser=1#scrollTo=SFEK8fuxPyo7


Resultado del modelo con las imágenes tomadas


Resultado del modelo con las imágenes tomadas


Arquitectura de implementación pensada originalmente

Nuevas Imágenes

Imágenes procesadas


Archivos


Estimación de Costos

# CGR-GIZ-CENFOTEC - Propuesta nueva arquitectura

AWS Cloud; Folder Diario; Archivos Amazon Elastic Container; Registry (Amazon ECR); Image; AWS Lambda; Lambda function; Amazon EventBridge; Rule; Amazon Elastic Container Registry (Amazon ECR); Amazon API Gateway; Endpoint

# CGR-GIZ-CENFOTEC - Costos Nueva arquitectura


Estimación de Costos

# Proyecto CGR-GIZ-CENFOTEC

## IA – Modelo y Estimación de implementación

Msc. Rodrigo Herrera

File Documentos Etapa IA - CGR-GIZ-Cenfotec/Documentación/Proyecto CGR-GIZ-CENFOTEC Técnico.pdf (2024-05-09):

## Proyecto CGR-GIZ-CENFOTEC Etapa - IA

Msc. Rodrigo Herrera

## CGR-GIZ-CENFOTEC

Objetivo

- Explicación técnica de etapa de Inteligencia Artificial Aplicada en detección de Objetos para monitoreo de las construcciones

Agenda

- Imágenes
- Proceso de Etiquetado
- Proceso de Entrenamiento del modelo
- Resultados del modelo
- Arquitectura de Implementación
- Configuraciones
- Resultados de la arquitectura


- Imágenes

- Proceso de Etiquetado


- Se etiquetan un total de
2,121 imágenes
- Se obtiene la siguiente
cantidad de etiquetas por
clase
- 751 Aplanadora
- 1,490 Persona
- 535 Tractor
- 445 Vagoneta
- 25 Mezcladora


- Proceso de Entrenamiento del modelo

Faster R-CNN

- Mayor efectividad en el proceso de

inferencia

- Resultados del modelo


- Resultados del modelo

Promedio de IoU: 82.7%
Recall: 85.4% (Verdaderos positivos)

Azul es la etiqueta y segmentación Rojo es la predicción

AWS Cloud; AWS Lambda; Lambda function; Amazon EventBridge; Rule; Amazon Elastic Container Registry (Amazon ECR); Image; Amazon S3

Folder Diario

Archivos

- Arquitectura de Implementación

- Configuración


- Resultados de la arquitectura


## Proyecto CGR-GIZ-CENFOTEC Etapa - IA

Msc. Rodrigo Herrera

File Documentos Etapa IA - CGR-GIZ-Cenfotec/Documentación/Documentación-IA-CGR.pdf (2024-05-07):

# Documentación del Sistema de Detección de Maquinaria en Obras de Construcción para la CGR

Bienvenid@ a la documentación del sistema de detección de maquinaria en obras de construcción para la Contraloría General de la República. En esta documentación encontrarás información detallada sobre la arquitectura del modelo de detección de objetos, la arquitectura del sistema dentro de AWS y la arquitectura de la imagen de Docker.

## Índice

Arquitectura del Modelo

Proceso de Entrenamiento

Configuración del Sistema en AWS

Configuración de Google Drive API

Estructura del Docker

# Arquitectura del Modelo

El modelo de detección de objetos en imágenes de maquinaria en obras de construcción se basa en FasterRCNN con ResNet50 como red base. FasterRCNN es un modelo de detección de objetos que consta de dos subredes: una red base y una red de detección. La red base es una red convolucional que se encarga de extraer características de la imagen de entrada, mientras que la red de detección es una red que se encarga de realizar la detección de objetos en la imagen.

ResNet50 es una red convolucional profunda que consta de 50 capas. Esta red es utilizada como red base en el modelo, ya que ha demostrado ser efectiva en la extracción de características de imágenes. FasterRCNN con ResNet50 como red base es un modelo de detección de objetos que ha demostrado ser efectivo en la detección de objetos en imágenes de maquinaria en obras de construcción.

La razón principal por la que se eligió ResNet50 como red base es porque es una red profunda que ha sido pre-entrenada en un gran conjunto de datos de imágenes. Esto significa que la red base ya ha aprendido a extraer características de alto nivel de las imágenes, lo que permite detectar objetos en las imágenes con alta precisión. Además, ResNet50 es una red profunda que ha demostrado ser efectiva en la extracción de características de imágenes, lo que la hace ideal para su uso como red base en el modelo de detección de objetos. Comparado con otros modelos, ResNet50 es más rápido y preciso en la detección de objetos en imágenes de maquinaria en obras de construcción.

El modelo de detección de objetos consta de las siguientes etapas:

1. Extracción de características: La red base (ResNet50) se encarga de extraer características de la imagen de entrada. La red base es una red convolucional profunda que ha sido pre-entrenada en un gran conjunto de datos de imágenes. Esta red es capaz de extraer características de alto nivel de la imagen de entrada, lo que permite detectar

objetos en la imagen.

2. Propuestas de regiones: Se generan propuestas de regiones en la imagen que pueden contener objetos. Estas propuestas se generan utilizando una red de detección que se entrena para predecir las regiones en las que es más probable que se encuentren objetos.
3. Extracción de características de las regiones propuestas: Se extraen características de las regiones propuestas utilizando la red base. Estas características se utilizan para clasificar las regiones propuestas en las diferentes clases de objetos.
4. Clasificación de las regiones propuestas: Se clasifican las regiones propuestas en las diferentes clases de objetos. Para ello, se utiliza un clasificador que se entrena para predecir la clase de objeto presente en cada región propuesta.
5. Predicción de las cajas delimitadoras de los objetos: Se predicen las cajas delimitadoras de los objetos en las regiones propuestas. Estas cajas delimitadoras se utilizan para localizar los objetos en la imagen y dibujar las cajas delimitadoras alrededor de los objetos detectados.

La ejemplificación de la arquitectura del modelo se muestra en la siguiente figura:


Una arquitectura como esta permite detectar y clasificar objetos en imágenes con alta precisión y rapidez, dando resultados similares a los que se observan en la siguiente imagen:


En nuestro caso, el modelo fue entrenado con imágenes que poseían uno o varios objetos representados pertenecientes a las siguentes clases o labels:

dump_truck

person

excavator

loader

mixer_truck

steamroller

Volver al inicio

# Proceso de Entrenamiento

Para el proceso de entrenamiento de un modelo de detección de objetos basado en Faster R-CNN con ResNet-50, se utilizó PyTorch y torchvision. A continuación, se detalla la arquitectura y el flujo de trabajo para el entrenamiento, evaluación y visualización de los resultados.

### Documentación del Código de Entrenamiento

Este código implementa un modelo de detección de objetos utilizando PyTorch y el modelo pre-entrenado Faster R-CNN basado en ResNet-50.

import torch
import torchvision
from torchvision.models.detection import fasterrcnn_resnet50_fpn, FasterRCNN_ResNet50_FPN_Weights
from torchvision.models.detection.faster_rcnn import FastRCNNPredictor from torchvision.transforms import functional as F
from torch.utils.data import Dataset, DataLoader
from torch.cuda.amp import GradScaler, autocast
from PIL import Image
import os
import json
import torchvision.transforms as transforms

os.environ['PYTORCH_CUDA_ALLOC_CONF'] = 'max_split_size_mb:128' os.environ['PYTORCH_CUDA_ALLOC_CONF'] = 'expandable_segments:True'

annotations_file = 'path/Train_dataset.json'

def class_text_to_int(class_text):

class_mapping = { "dump_truck": 1,"person": 2,"excavator": 3,"loader": 4,"mixer_truck": 5,"steamroller": 6}
return class_mapping.get(class_text, None)

class CustomDataset(Dataset):
def __init__(self, annotations_file, img_dir, transform=None): with open(annotations_file) as f:
self.img_labels = json.load(f)
self.img_dir = img_dir
self.transform = transform if transform is not None else transforms.Compose([
transforms.ToTensor(), # Converts PIL images to PyTorch tensors
])

def __len__(self):
return len(self.img_labels['images'])

def __getitem__(self, idx):
img_path = os.path.join(self.img_dir, self.img_labels['images'] [idx]['image_path'])
image = Image.open(img_path).convert("RGB")
# Apply transformations

if self.transform:
image = self.transform(image)
objects = self.img_labels['images'][idx]['objects'] boxes = []
labels = []
for obj in objects:
xmin, ymin, xmax, ymax = obj['bbox'].values() boxes.append([xmin, ymin, xmax, ymax]) labels.append(class_text_to_int(obj['class'])) boxes = torch.as_tensor(boxes, dtype=torch.float32)

labels = torch.as_tensor(labels, dtype=torch.int64) target = {"boxes": boxes, "labels": labels}
return image, target

def get_model(num_classes):
model =
fasterrcnn_resnet50_fpn(weights=FasterRCNN_ResNet50_FPN_Weights.DEFAULT) in_features = model.roi_heads.box_predictor.cls_score.in_features model.roi_heads.box_predictor = FastRCNNPredictor(in_features, num_classes)
return model

def collate_fn(batch):
return tuple(zip(*batch))

def train_one_epoch(model, optimizer, data_loader, device, epoch, accumulation_steps=4):
model.train()
scaler = GradScaler()
optimizer.zero_grad()
for i, (images, targets) in enumerate(data_loader):
images = [image.to(device) for image in images]
targets = [{k: v.to(device) for k, v in t.items()} for t in targets]
with autocast():
loss_dict = model(images, targets)
losses = sum(loss for loss in loss_dict.values()) / accumulation_steps
scaler.scale(losses).backward()
if (i + 1) % accumulation_steps == 0 or (i + 1) == len(data_loader):

1. Importaciones:
Importa las librerías necesarias incluyendo PyTorch, torchvision, PIL para manejo de imágenes, y otras utilidades de sistema y JSON para manejar archivos y configuraciones.
2. Configuraciones de CUDA:
Establece variables de entorno para optimizar la asignación de memoria en CUDA de PyTorch.

scaler.step(optimizer)
scaler.update()
optimizer.zero_grad()
print(f"Epoch #{epoch} pérdida: {losses.item()}")

def main():
device = torch.device('cuda' if torch.cuda.is_available() else 'cpu') num_classes = 7
dataset = CustomDataset(annotations_file, 'path/Images_etiquetadas', transform=None)

data_loader = DataLoader(dataset, batch_size=24, shuffle=True, collate_fn=collate_fn, num_workers=20, pin_memory=True)

model = get_model(num_classes).to(device)
optimizer = torch.optim.SGD(model.parameters(), lr=0.005, momentum=0.9)
#optimizer = torch.optim.Adam(model.parameters(), lr=0.001)

num_epochs = 100
for epoch in range(num_epochs):
train_one_epoch(model, optimizer, data_loader, device, epoch) torch.save(model.state_dict(), f'path/model_epoch_{epoch}.pth',)

if __name__ == "__main__": main()

3. Archivo de anotaciones:
Define la ruta al archivo JSON que contiene las anotaciones del dataset.
4. Clase CustomDataset CustomDataset :

Constructor: Carga las anotaciones de un archivo JSON y establece el directorio de imágenes y transformaciones opcionales.

__len__ __len__ : Retorna el número de imágenes en el dataset.

__getitem__ __getitem__ : Carga y transforma una imagen del dataset, extrae las cajas de delimitación y las etiquetas de las clases de los objetos presentes en la imagen, y retorna la imagen y los objetivos (etiquetas y cajas).
5. Funciones:

Función class_text_to_int class_text_to_int :
Convierte el texto de la clase de un objeto a un entero según un mapeo predefinido.

Función get_model get_model :
Carga el modelo Faster R-CNN preentrenado y modifica el predictor para ajustarse al número de clases proporcionado.

Función collate_fn collate_fn :
Función auxiliar para agrupar los datos procesados en un batch.

Función train_one_epoch train_one_epoch :
Entrena el modelo por una época. Utiliza GradScaler para manejar la precisión mixta durante el entrenamiento, ayudando a mejorar el rendimiento y reducir el uso de memoria. Realiza la propagación hacia atrás y actualiza los pesos del modelo.

Función main main :
Establece el dispositivo de entrenamiento (GPU o CPU). Prepara el dataset y el cargador de datos. Crea el modelo y el optimizador. Ejecuta el entrenamiento del modelo para un número definido de épocas y guarda los pesos del modelo después de cada época.
6. Bloque de ejecución: Verifica si el script se ejecuta como archivo principal y, de ser así, ejecuta la función main.

### Documentación de Código de Evaluación

Este código implementa un proceso de evaluación para el modelo de objetos basado en Faster R-CNN con ResNet-50 usando PyTorch y torchvision.

import torch
import torchvision
from torchvision.models.detection import fasterrcnn_resnet50_fpn, FasterRCNN_ResNet50_FPN_Weights
from torchvision.models.detection.faster_rcnn import FastRCNNPredictor from torchvision.transforms import functional as F
from torch.utils.data import Dataset, DataLoader
from PIL import Image
import os
import json
import torchvision.transforms as transforms import numpy as np

def collate_fn(batch):
return tuple(zip(*batch))

def class_text_to_int(class_text): class_mapping = {
"dump_truck": 1,
"person": 2,
"excavator": 3,
"loader": 4,
"mixer_truck": 5,
"steamroller": 6
}
return class_mapping.get(class_text, None)

class CustomDataset(Dataset):
def __init__(self, annotations_file, img_dir, transform=None):

with open(annotations_file) as f:
self.img_labels = json.load(f)
self.img_dir = img_dir
self.transform = transform if transform is not None else transforms.Compose([
transforms.ToTensor(),
])

def __len__(self):
return len(self.img_labels['images'])

def __getitem__(self, idx):
img_info = self.img_labels['images'][idx]
img_path = os.path.join(self.img_dir, img_info['image_path']) image = Image.open(img_path).convert("RGB")

if self.transform:
image = self.transform(image)

boxes = []
labels = []
for obj in img_info['objects']:
bbox = obj['bbox']
boxes.append([bbox['x_min'], bbox['y_min'], bbox['x_max'], bbox['y_max']])
labels.append(class_text_to_int(obj['class']))

boxes = torch.as_tensor(boxes, dtype=torch.float32) labels = torch.as_tensor(labels, dtype=torch.int64) target = {"boxes": boxes, "labels": labels}

return image, target

def bbox_iou(box1, box2):
x1 = max(box1[0], box2[0]) y1 = max(box1[1], box2[1])
x2 = min(box1[2], box2[2])
y2 = min(box1[3], box2[3])
inter_area = max(x2 - x1, 0) * max(y2 - y1, 0)
box1_area = (box1[2] - box1[0]) * (box1[3] - box1[1]) box2_area = (box2[2] - box2[0]) * (box2[3] - box2[1])
iou = inter_area / float(box1_area + box2_area - inter_area) return iou

def get_model(num_classes):
model =
fasterrcnn_resnet50_fpn(weights=FasterRCNN_ResNet50_FPN_Weights.DEFAULT) in_features = model.roi_heads.box_predictor.cls_score.in_features model.roi_heads.box_predictor = FastRCNNPredictor(in_features, num_classes)
return model

device = torch.device('cuda' if torch.cuda.is_available() else 'cpu')

Pocosi_24042024_30epocs = 'path/model.pth'
model = get_model(num_classes=7) model.load_state_dict(torch.load(Pocosi_24042024_30epocs, map_location=device))
model = model.to(device)
model.eval()

test_annotations_file = 'path/test_dataset.json'
images_path = 'path/Images_etiquetadas'
test_dataset = CustomDataset(test_annotations_file, images_path) test_loader = DataLoader(test_dataset, batch_size=1, shuffle=False, collate_fn=collate_fn)

ious = []
true_positives, false_positives, false_negatives = 0, 0, 0 iou_threshold = 0.7

for images, targets in test_loader:
images = [image.to(device) for image in images]
outputs = model(images)
for i, output in enumerate(outputs):
predicted_boxes = output['boxes'].data.cpu().numpy() predicted_labels = output['labels'].data.cpu().numpy() target_boxes = targets[i]['boxes'].data.cpu().numpy() target_labels = targets[i]['labels'].data.cpu().numpy()

matched_gt = set()
for pb_idx, predicted_box in enumerate(predicted_boxes): for tb_idx, target_box in enumerate(target_boxes):
iou = bbox_iou(predicted_box, target_box)
if iou > iou_threshold and tb_idx not in matched_gt: matched_gt.add(tb_idx)
ious.append(iou)
if predicted_labels[pb_idx] == target_labels[tb_idx]: true_positives += 1
else:
false_positives += 1
break
else:
false_positives += 1
false_negatives += len(target_boxes) - len(matched_gt)

average_iou = sum(ious) / len(ious) if ious else 0
precision = true_positives / (true_positives + false_positives) if true_positives + false_positives > 0 else 0
recall = true_positives / (true_positives + false_negatives) if true_positives + false_negatives > 0 else 0

1. Importaciones: Se importan las librerías necesarias como PyTorch, torchvision, PIL para manejo de imágenes, numpy para operaciones numéricas, y otras para el manejo de archivos y transformaciones
2. Funciones y Clases:

collate_fn collate_fn : Función que ayuda a agrupar los elementos de datos en un lote, necesario para el cargador de datos.

class_text_to_int class_text_to_int : Mapea el texto de clasificación de objetos a un número entero para su procesamiento.

CustomDataset CustomDataset : Define un dataset personalizado que carga y transforma imágenes y etiquetas de un archivo JSON, y prepara los datos para el entrenamiento o evaluación.

bbox_iou bbox_iou : Calcula la Intersección sobre Unión (IoU) de dos cajas delimitadoras, útil para evaluar la precisión de las predicciones del modelo.

get_model get_model : Carga y modifica un modelo Faster R-CNN preentrenado para adaptarlo al número específico de clases.
3. Carga del Modelo:

Establece el dispositivo de cálculo (CPU o GPU).

Carga los pesos de un modelo previamente entrenado desde un archivo guardado.

Cambia el modelo al modo de evaluación, desactivando características como Dropout o BatchNorm durante las predicciones.
4. Definición del Dataset de Prueba:

Define el archivo de anotaciones y la ruta de las imágenes para el conjunto de datos de prueba.

Carga el dataset de prueba usando la clase | CustomDataset | y prepara un cargador
de datos para iterar sobre el dataset.

print(f"Average IoU: {average_iou:.2f}") print(f"Precision: {precision:.2f}") print(f"Recall: {recall:.2f}")

5. Evaluación del Modelo:

Inicializa variables para contar verdaderos positivos, falsos positivos, y falsos negativos, y calcula la precisión (precision), el recall y el IoU medio de las predicciones.

Itera sobre el conjunto de datos de prueba, realiza predicciones con el modelo y compara las cajas predichas con las cajas verdaderas basándose en el umbral de IoU.

Calcula y actualiza las métricas de verdaderos positivos, falsos positivos y falsos negativos basándose en la coincidencia de las etiquetas y la IoU.

Al final del proceso, imprime el IoU medio, la precisión y el recall.

### Código para Visualizar los Resultados

Este código en Python utiliza Matplotlib para visualizar predicciones y verdades de tierra (ground truth) de un modelo de detección de objetos sobre imágenes. A continuación, la explicación en español del código:

import matplotlib.pyplot as plt
import matplotlib.patches as patches

# Función para graficar las imágenes def draw_boxes(ax, boxes, labels, color): for box, label in zip(boxes, labels):

x1, y1, x2, y2 = box
rect = patches.Rectangle((x1, y1), x2 - x1, y2 - y1, linewidth=2, edgecolor=color, facecolor='none') ax.add_patch(rect)
ax.text(x1, y1, label, verticalalignment='bottom', horizontalalignment='left', color=color, fontsize=12)

# Figura de visualización

fig, axes = plt.subplots(20, 1, figsize=(30, 50)) # 1 row, 5 columns image_counter = 0

test_annotations_file = 'path/test_dataset.json'

# Carga datos

test_dataset = CustomDataset(test_annotations_file, images_path, transform=None)
test_loader = DataLoader(test_dataset, batch_size=1, shuffle=False, collate_fn=collate_fn)

for images, targets in test_loader:
images = [image.to(device) for image in images] outputs = model(images)

for i, image in enumerate(images):
if image_counter >= 20:
break

ax = axes[image_counter]
img = F.to_pil_image(image.cpu()) ax.imshow(img)

# Cajas reales

target_boxes = targets[i]['boxes'].cpu().numpy() target_labels = [str(label) for label in targets[i] ['labels'].cpu().numpy()]
draw_boxes(ax, target_boxes, target_labels, 'blue')

#Cajas Predichas

predicted_boxes = outputs[i]['boxes'].detach().cpu().numpy() predicted_scores = outputs[i]['scores'].detach().cpu().numpy() predicted_labels = [str(label) for label in outputs[i] ['labels'].detach().cpu().numpy()]

1. Importaciones: Se importa | matplotlib.pyplot | para la creación de gráficos y
matplotlib.patches | para dibujar rectángulos, que representarán las cajas
delimitadoras.
2. Función draw_boxes draw_boxes : Dibuja cajas delimitadoras sobre una imagen y etiqueta cada caja. Recibe un eje de Matplotlib ( ax ), las cajas ( boxes ), las etiquetas asociadas
( labels ) y un color especificado ( color ). Por cada caja y etiqueta:

Calcula las coordenadas del rectángulo.

Crea y añade un rectángulo al eje.

Añade texto que representa la etiqueta de la clase en la esquina superior izquierda de la caja.
3. Inicialización de la Figura:

Se crea una figura y un conjunto de ejes usando subplots , configurados para mostrar 20 imágenes en una columna.

high_score_idxs = [idx for idx, score in enumerate(predicted_scores) if score > 0.7] predicted_boxes = predicted_boxes[high_score_idxs] predicted_labels = [predicted_labels[idx] for idx in high_score_idxs]

draw_boxes(ax, predicted_boxes, predicted_labels, 'red')

ax.axis('off')
image_counter += 1

if image_counter >= 20:
break

plt.tight_layout()
plt.show()

4. Carga de Datasets y DataLoader:

Define el archivo y ruta para el conjunto de datos de prueba.

Utiliza la clase | CustomDataset | para cargar el conjunto de datos y el | DataLoader
para iterar sobre él.
5. Iteración sobre el DataLoader:

Para cada lote de imágenes y objetivos del DataLoader:

Se transfieren las imágenes al dispositivo adecuado (GPU o CPU).

Se obtienen las predicciones del modelo.

Para cada imagen y sus predicciones:

Si ya se han procesado 20 imágenes, se detiene el bucle.

Se convierte la imagen tensorial a imagen PIL para visualización.

Se visualizan las cajas delimitadoras de las verdades de tierra (color azul) y las predicciones (color rojo), utilizando la función draw_boxes .

Se filtran las predicciones para mostrar solo aquellas con un puntaje superior al 70%.

Se desactivan los ejes para una visualización más limpia.

6. Visualización de Resultados:

Se ajustan automáticamente los subplots para que se adapten al layout de la figura.

Se muestra la figura con todas las imágenes y sus correspondientes cajas delimitadoras superpuestas.

Volver al inicio

# Configuración del Sistema en AWS

El sistema de detección de maquinaria en obras de construcción para la Contraloría General de la República se encuentra desplegado en la nube de Amazon Web Services (AWS). La arquitectura del sistema en AWS se compone de los siguientes servicios:

1. Amazon Elastic Container Registry (ECR): ECR es un servicio de AWS que permite almacenar, administrar y desplegar imágenes de contenedores de Docker. En el sistema, se utiliza ECR para almacenar la imagen de Docker que contiene el modelo de detección de objetos y los archivos de configuración necesarios para realizar las inferencias.
2. Amazon Lambda: Lambda es un servicio de AWS que permite ejecutar código sin tener que aprovisionar ni administrar servidores. En el sistema, se utiliza Lambda para ejecutar el modelo de detección de objetos y realizar las inferencias sobre las imágenes de maquinaria en obras de construcción.
3. Amazon EventBridge: EventBridge es un servicio de AWS que permite conectar aplicaciones con eventos generados por servicios de AWS, aplicaciones de software o eventos personalizados. En el sistema, se utiliza EventBridge para programar la ejecución del modelo de detección de objetos a través de un scheduler.
4. Amazon IAM: IAM es un servicio de AWS que permite gestionar el acceso a los recursos de AWS de forma segura. En el sistema, se utiliza IAM para definir los roles y permisos necesarios para que los servicios de AWS puedan interactuar entre sí.
5. Amazon S3: S3 es un servicio de AWS que permite almacenar y recuperar datos de forma segura y escalable. En el sistema, se utiliza S3 para almacenar el token.picle que permite acceder a la API de Google Drive y las imágenes de maquinaria en obras de construcción sobre las cuales se realizarán las inferencias.

La arquitectura de AWS se muestra representada visualmente en la siguiente figura:


## Configuración de los Servicios en AWS

A continuación se detallan los pasos necesarios para configurar el cada uno de los servicios en AWS:

### Amazon Elastic Container Registry (ECR)

Instalación de AWS Tools para PowerShell

1. Abrir PowerShell con derechos de administrador:

Para instalar AWS Tools para PowerShell, ejecute el siguiente comando:

Si se necesita configurar una versión anterior, utilizar:

2. Importar el Módulo AWS PowerShell:

Luego de la instalación, importar el módulo con:

Install-Module -Name AWS.Tools.Common Install-Module -Name AWS.Tools.ECR

Install-Module -Name AWSPowerShell

3. Verificación de la Instalación:
Comprobar que el cmdlet | Get-ECRLoginCommand | está disponible mediante:

En caso de tener errores al ejecutar los comandos de importación tras la instalación, es posible que sea a causa de los permisos de Windows. Para solucionar esto, se deben ejecutar los siguientes comandos:

El resultado debería de ser similar a la imagen:

4. Configuración de Credenciales de AWS:

Una vez el usuario IAM esté creado, obtener las claves de acceso. Configurar las credenciales con:

Establecer las credenciales en PowerShell, reemplazando | YOUR_ACCESS-KEY | y
YOUR_SECRET-KEY | por las credenciales correspondientes:

Import-Module AWS.Tools.Common Import-Module AWS.Tools.ECR

Get-Command Get-ECRLoginCommand

Get-ExecutionPolicy
Set-ExecutionPolicy RemoteSigned Import-Module AWS.Tools.Common Import-Module AWS.Tools.ECR Get-Command Get-ECRLoginCommand

aws configure

5. Inicio de Sesión en ECR:

Utilizar el comando para iniciar sesión en ECR con Docker:

El resultado debería de ser similar a la imagen:

Uso de Docker con ECR

Finalmente, se puede navegar al path donde se encuentra el archivo | Dockerfile | y ejecutar
los comandos proveídos por ECR, como el comando para construir la imagen de Docker:

El resultado debería de ser similar a la imagen:

Set-AWSCredential -AccessKey YOUR_ACCESS_KEY -SecretKey YOUR_SECRET_KEY -StoreAs default

(Get-ECRLoginCommand -Region us-east-1).Password | docker login --
username AWS --password-stdin YOUR_ID.dkr.ecr.us-east-1.amazonaws.com

docker build -t contraloria_testecr .


### Amazon Lambda

Utilización de la Imagen Docker desde Lambda

Una vez que la imagen de Docker ha sido construida y subida a ECR, se puede utilizar desde Lambda. Para ello, se debe crear una función de Lambda y configurarla para que utilice la imagen de Docker almacenada en ECR, con las siguientes configuraciones:

### Amazon EventBridge

Crear Reglas de Evento

Se configura una regla de evento en EventBridge para programar la ejecución de la función de Lambda que utiliza la imagen de Docker almacenada en ECR. Esta regla se configura para que se ejecute periódicamente según un cronograma definido, por ejemplo, todos los días a las 8 PM UTC, que corresponde a las 6 PM en Costa Rica, tal y como se ve en la imagen:


### Amazon IAM

Crear y Gestión de Políticas

Se utiliza IAM para definir políticas de seguridad que controlen el acceso a los recursos de AWS. Esto incluye la creación de roles y la asignación de políticas a esos roles para permitir o restringir acciones específicas en los servicios de AWS, tal y como se ve en la imagen:


### Amazon S3

Almacenamiento del Token de Google Drive

Se utiliza S3 para almacenar el token.pickle que permite acceder a la API de Google Drive y las imágenes de maquinaria en obras de construcción sobre las cuales se realizarán las inferencias. Para ello, se crea un bucket de S3 y define que sea público, tal y como se ve en las imágenes:



## Configuración del API

La estructura del API se constituye para seguir el siguiente flujo de procesos:

1. Envío de Imágenes por Usuarios Externos: Los usuarios externos envían imágenes de obras de construcción a un endpoint definido dentro del API Gateway, en un formato de Base64.
2. Amazon API Gateway: El API Gateway recibe las imágenes de obras de construcción, las enruta y envía a la función de Lambda, para ser procesadas.
3. Amazon Lambda: La función de Lambda recibe las imágenes de obras de construcción. Posteriormente, utiliza el contenedor de Docker almacenado en ECR para realizar las inferencias sobre las imágenes y detectar la maquinaria en obras de construcción.
4. Amazon Elastic Container Registry (ECR): ECR almacena la imagen de Docker que contiene el modelo de detección de objetos y los archivos de configuración necesarios para realizar las inferencias. La imagen de Docker es utilizada por la función de Lambda para realizar las inferencias sobre las imágenes de maquinaria en obras de construcción.

5. Procesamiento y Respuesta: La función de Lambda procesa las imágenes de obras de construcción y detecta la maquinaria en obras de construcción. Posteriormente, envía la respuesta con las inferencias obtenidas mediante el modelo almacenado dentro del contenedor al API Gateway.
6. Respuesta a Usuarios Externos: El API Gateway recibe la respuesta con las inferencias obtenidas y la envía a los usuarios externos que enviaron las imágenes de obras de construcción.

La estructura del API se muestra representada visualmente en la siguiente figura:


Volver al inicio

# Configuración de Google Drive API

Para la configuración de Google Drive API, se debe ir a la consola de Google Cloud, crear un proyecto y seleccionarlo. Luego, ir a la sección de API y Servicios y habilitar la API de Google Drive para el proyecto. Posteriormente, ir a la opción de Administrar para crear credenciales para usar la API.


A la hora de crear las credenciales, se debe seleccionar la opción de Datos de Usuario y dar un nombre a la aplicación. Se debe ingresar el correo electrónico donde se requiera. Se debe establecer el tipo de aplicación como Aplicación de Escritorio y descargar el archivo de secretos del cliente que se proporciona en el último paso.


Ahora que el ID de cliente de OAuth está creado, se debe crear una cuenta de servicio y conceder acceso de owner a la Service Account. Finalmente, se genera una API key y se establecen las restricciones de la API de Google Drive.

Con esto, la configuración está completa. Se selecciona una carpeta de Drive y se guarda su ID para más adelante. Se puede encontrar navegando a la carpeta y mirando la URL.

Una vez que se tiene el JSON de credenciales, se debe ejectutar el archivo start_connection.py , el cual se encuentra documentado a continuación.

Documentación de Archivo Start_Connection.py Start_Connection.py

Este código en Python implementa la autenticación y acceso a Google Drive utilizando la API de Google Drive.

from google_auth_oauthlib.flow import InstalledAppFlow
from googleapiclient.discovery import build
from google.auth.transport.requests import Request import pickle
import os
import io

# Scope son los permisos de acceso que se dan para leer o escribir archivos en el google drive.

SCOPES = ['https://www.googleapis.com/auth/drive']

def main():
creds = None
# El archivo de token.pickle es el que almacena la información del usuario, este es creado automaticamente cuuando

# el proceso de autenticacón sucede por primera vez.

if os.path.exists('token.pickle'):
pickle_data = b"token.pickle"
byte_stream = io.BytesIO(pickle_data)
creds = pickle.load(pickle_data)
print("Pickle read")

# Si el archivo token.pickle no es encontrado, este direcciona a realizarse la authenticación desde la web.

if not creds or not creds.valid:
if creds and creds.expired and creds.refresh_token: creds.refresh(Request())
else:
flow =
InstalledAppFlow.from_client_secrets_file('client_secret.json', SCOPES) #Archivo json creado desde GCP
creds = flow.run_local_server(port=0) # Save the credentials for the next run with open('token.pickle', 'wb') as token: pickle.dump(creds, token)

service = build('drive', 'v3', credentials=creds)

# Ejemplo para probar el acceso

results = service.files().list(
pageSize=10, fields="nextPageToken, files(id, name)").execute() items = results.get('files', [])

if not items:

print('Archivos no encontrados.') else:
print('Archivos:')
for item in items:
print(f"{item['name']} ({item['id']})")

if __name__ == '__main__': main()

'''
#Código para probar el funcionamiento del pickle y traerlo desde S3 a el Lambda

def load_pickle_from_s3(bucket_name, object_key):

# Creando el boto3

s3_client = boto3.client('s3')

try:

response = s3_client.get_object(Bucket=bucket_name, Key=object_key)
file_content = response['Body'].read()
data_stream = io.BytesIO(file_content)
data = pickle.load(data_stream) return data

except Exception as e:
print(f"Falla traer el pickle de S3: {e}") return None
# Ejemplo de USO

bucket = 'S3_BUCKET_NAME' #puede variar key = 'token.pickle'

1. Importaciones:

google_auth_oauthlib.flow google_auth_oauthlib.flow : Importa InstalledAppFlow , utilizado para manejar el flujo de autenticación con OAuth 2.0.

googleapiclient.discovery googleapiclient.discovery : Importa | build | para construir un objeto de
servicio que interactúa con la API de Google.
google.auth.transport.requests google.auth.transport.requests : Importa | Request | para manejar solicitudes
HTTP durante el proceso de autenticación.

pickle pickle : Se utiliza para serializar y deserializar objetos Python, permitiendo guardar y cargar credenciales.

osos | y | ioio : Utilizados para manejo de archivos y flujos de bytes en memoria,
respectivamente.
2. Constantes:

SCOPES SCOPES : Define los permisos necesarios para acceder a los archivos de Google Drive. En este caso, el permiso es para leer y escribir archivos.

3. Función main main :

Manejo de credenciales:

Verifica si existe un archivo | token.pickle | que contiene credenciales
previamente guardadas. Si existe, las carga para evitar la necesidad de autenticarse nuevamente.

Si las credenciales no son válidas o han expirado, y existe un refresh_token , intenta actualizar las credenciales. De lo contrario, inicia el flujo de autenticación para obtener nuevas credenciales.

data = load_pickle_from_s3(bucket, key) if data:
print("Se carga el pickle")
else:
print("Falla en carga de pickle")

'''

Flujo de Autenticación:

Utiliza | InstalledAppFlow | para iniciar un proceso de autenticación en caso de no
encontrar credenciales válidas. Este proceso abrirá una ventana del navegador para que el usuario inicie sesión y autorice la aplicación.
Guarda las nuevas credenciales en | token.pickle | para futuras ejecuciones.

Construcción del Servicio:

Crea un objeto de servicio para interactuar con la API de Google Drive, utilizando las credenciales obtenidas.
Listado de Archivos:

Utiliza el servicio para listar los primeros 10 archivos en Google Drive, mostrando su nombre y ID.

Imprime los archivos encontrados, o un mensaje indicando que no se encontraron archivos si la lista está vacía.
4. Ejecución:
Si este script es el archivo principal que se está ejecutando | (__name__ ==
'__main__') , entonces llama a la función | main .

Volver al inicio

# Estructura del Docker

El sistema de detección de maquinaria en obras de construcción se encuentra encapsulado en una imagen de Docker. La imagen de Docker contiene el modelo de detección de objetos, los archivos de configuración necesarios para realizar las inferencias y las dependencias del sistema. La imagen de Docker se utiliza para desplegar el sistema en cualquier entorno de desarrollo o producción de forma rápida y sencilla.

La imagen de Docker se compone de los siguientes elementos:


### Documentación del Código de Inferencia run_inference.py run_inference.py

Este código en Python integra varias tecnologías incluyendo PyTorch, AWS S3, Google Drive API y Pandas para realizar tareas de inferencia con un modelo de detección de objetos y gestionar la salida en la nube.

import os
# TORCH_HOME environment en '/tmp' es necesario para la escritura en Lambda

os.environ['TORCH_HOME'] = '/tmp'

from google_auth_oauthlib.flow import InstalledAppFlow from google.auth.transport.requests import Request import pickle
import os
import torch
from torchvision.models.detection import fasterrcnn_resnet50_fpn, FasterRCNN_ResNet50_FPN_Weights
from torchvision.models.detection.faster_rcnn import FastRCNNPredictor from torchvision.transforms import functional as F
from PIL import Image
from googleapiclient.discovery import build
from googleapiclient.http import MediaFileUpload from datetime import datetime
import io
import pandas as pd
import boto3
import csv
from io import StringIO
from googleapiclient.http import MediaIoBaseUpload

#["dump_truck", "person", "excavator", "loader", "mixer_truck",'steamroller']

class_mapping = ["Vagoneta", "Persona", "Tractor", "Cargador", "Mezcladora",'Aplanadora']
print(class_mapping)

#Definir el umbral de aceptación. threshold = 0.7

num_classes = 7

FOLDER_ID = '1' #folderID de dIAra Account

#Función para imporar el token.pickle desde S3 def load_pickle_from_s3(bucket_name, object_key):

s3_client = boto3.client('s3')
try:
response = s3_client.get_object(Bucket=bucket_name, Key=object_key)
file_content = response['Body'].read()
data_stream = io.BytesIO(file_content)
data = pickle.load(data_stream) print("Pickle Cargado")
return data
except Exception as e:
print(f"Falla en cargar pickle desde S3: {e}") return None

#Función para guardar archivo en S3 y despues transferir a Google Drive def save_csv_to_s3_movetogdrive(data):

s3_client = boto3.client('s3')
csv_buffer = StringIO()
data.to_csv(csv_buffer, index=False)

print(csv_buffer.getvalue(), "primer") csv_buffer.seek(0)

today = datetime.now()
formatted_date = today.strftime('%Y%m%d') formatted_date
print(formatted_date)

bucket_name = 'c'
object_key = f'{formatted_date}.csv' s3_client.put_object(Bucket=bucket_name, Key=object_key, Body=csv_buffer.getvalue(), ContentType='text/csv')
print( f' Archivo Cargado satisfactoriamente {object_key} a {bucket_name}')

#Enviar archivo de S3 a Drive

s3_client = boto3.client('s3')
s3_response = s3_client.get_object(Bucket = bucket_name, Key= object_key)
file_data = s3_response['Body'].read()
file_stream = io.BytesIO(file_data)
key = 'token.pickle'
creds = load_pickle_from_s3(bucket_name, key) service = build('drive', 'v3', credentials=creds)
archivos_folderID = '1' #Folder ID de Archivos dIAra

file_metadata = { 'name' : object_key, 'parents': [archivos_folderID] }
media = MediaIoBaseUpload(file_stream,mimetype='application/octet-stream', resumable=True)

try:
file = service.files().create(body=file_metadata, media_body=media,
fields='id').execute()
if 'id' in file:
print(f"Archivo cargado con el ID: {file['id']}") except Exception as e:
print(f"Error: {e}")

#Función para enlistar a todos los archivos que estan en la carpeta del día y trae las credenciales

def list_files(folder_id):

today = datetime.now()
formatted_date = today.strftime('%Y%m%d') formatted_date
print(formatted_date)

SCOPES = ['https://www.googleapis.com/auth/drive']

bucket = 'c'
key = 'token.pickle'
creds = load_pickle_from_s3(bucket, key)

service = build('drive', 'v3', credentials=creds) query = f"'{folder_id}' in parents"
result = service.files().list(q=query).execute() files = result.get('files', [])

imgs_id = []

for file in files:
folder = file['name']
id_folder = file['id']
if folder.find('.') == -1:
if folder == formatted_date:
query = f"'{id_folder}' in parents and mimeType != 'application/vnd.google-apps.folder'" result = service.files().list(q=query).execute() imgs = result.get('files', [])
for img in imgs:
if img['name'].find('.') != -1: imgs_id.append([img['name'], img['id']]) break
return imgs_id, formatted_date, creds

#Función para leer la arquitectura base de FasterRCNN

def get_model(num_classes, weights_path='./fasterrcnn_resnet50_fpn.pth'): model = fasterrcnn_resnet50_fpn(pretrained=False) model.load_state_dict(torch.load(weights_path))
in_features = model.roi_heads.box_predictor.cls_score.in_features model.roi_heads.box_predictor = FastRCNNPredictor(in_features, num_classes)
return model

#Función principal para inferir en los archivos leidos desde google drive def main():

img_inference, formatted_date, creds = list_files(FOLDER_ID) print(img_inference)
if img_inference != []:
#Cargar el modelo deseado (tomar en cuante las transformaciones) model = get_model(num_classes) model.load_state_dict(torch.load('./model_epoch_99.pth', map_location=torch.device('cpu'))) model.eval()

device = torch.device('cuda') if torch.cuda.is_available() else torch.device('cpu')
model = model.to(device)

imgs_name = []
img_clase = []
img_prob = []
img_bbox = []

#Proceso de inferencia y crear archivo de resultados service = build('drive', 'v3', credentials=creds) for img_name, img_id in img_inference: file_metadata =

service.files().get_media(fileId=img_id).execute() file = io.BytesIO(file_metadata)
img_pil = Image.open(file)
img_tensor = F.to_tensor(img_pil).unsqueeze(0) image = img_tensor.to(device)
with torch.no_grad():

1. Importaciones y Configuraciones Iniciales:

Importa las bibliotecas necesarias para trabajar con archivos, modelos de aprendizaje automático, manejo de imágenes, acceso a Google Drive, y almacenamiento en AWS S3.

Establece la ruta para la caché de modelos de PyTorch usando os.environ['TORCH_HOME'] .

2. Variables y Funciones:

prediction = model(image)
bboxes = prediction[0]['boxes']
labels = prediction[0]['labels']
scores = prediction[0]['scores']
for bbox, label, score in zip(bboxes, labels, scores): if score > threshold:
objeto = class_mapping[int(label)-1] print(f"Imagen: {img_name}, se encontro: el objeto {objeto}, bbox {bbox}, score = {score}") imgs_name.append(img_name) img_clase.append(objeto)
img_prob.append(score)
img_bbox.append(bbox)

data = pd.DataFrame()
data["nombre_imagen"] = imgs_name data["clase"] = img_clase
data["probabilidad"] = img_prob data["recuadro"] = img_bbox

save_csv_to_s3_movetogdrive(data)

if __name__ == '__main__': main()

class_mapping class_mapping : Un arreglo que mapea índices a nombres de clases para las detecciones del modelo.

threshold, num_classes, FOLDER_ID threshold, num_classes, FOLDER_ID : Variables para configurar el umbral de detección, el número de clases y el ID del folder en Google Drive.
3. Funciones de Manejo de Datos en S3 y Google Drive:

load_pickle_from_s3 load_pickle_from_s3 : Carga un archivo pickle desde un bucket de S3, utilizado para manejar credenciales de autenticación.

save_csv_to_s3_movetogdrive save_csv_to_s3_movetogdrive : Guarda un DataFrame de Pandas como un archivo CSV en S3 y luego lo transfiere a Google Drive.

list_files list_files : Lista archivos en una carpeta específica de Google Drive y carga credenciales desde S3.
4. Función para Cargar y Configurar el Modelo de Detección:

get_model get_model : Carga y configura un modelo de detección de objetos Fasterrcnn ResNet50, ajustando el predictor de clases según el número de clases proporcionado.

5. Función Principal main main :

Realiza una lista de imágenes a inferir desde una carpeta específica en Google Drive.

Carga y configura el modelo para realizar inferencias sobre las imágenes listadas.

Para cada imagen:

Descarga la imagen desde Google Drive.

Realiza la inferencia utilizando el modelo de PyTorch.

Guarda los resultados de la inferencia (clase, probabilidad, y bbox) en listas.

Crea un DataFrame con los resultados y lo guarda en S3, transfiriéndolo luego a Google Drive.
6. Ejecución:

Si el script se ejecuta como el archivo principal, se invoca la función main .

### Documentación del Docker File

El | Dockerfile | es un archivo de configuración que contiene las instrucciones necesarias para
construir la imagen de Docker. Se especifica la imagen base, las dependencias del sistema, y los archivos de configuración necesarios para realizar las inferencias usando PyTorch con soporte para GPU.
1. FROM pytorch/pytorch:2.2.1-cuda12.1-cudnn8-runtime :

Esta línea especifica la imagen base que se usará para construir la nueva imagen Docker. La imagen base es una versión oficial de PyTorch preconfigurada con CUDA 12.1 y cuDNN 8 para soporte de GPU. Esto facilita el desarrollo y despliegue de aplicaciones de PyTorch que requieren aceleración por GPU.

2. WORKDIR /app :

Establece el directorio de trabajo dentro del contenedor Docker. Todos los comandos que
se ejecuten posteriormente en el | Dockerfile | se realizarán en este directorio | /app .
3. COPY . /app :

Copia todos los archivos del directorio actual en la máquina host (donde se está
construyendo la imagen Docker) al directorio | /app | dentro del contenedor. Esto incluye
todos los scripts, archivos de código, y otros recursos necesarios para ejecutar la aplicación.
4. RUN pip install -r requirements.txt :

FROM pytorch/pytorch:2.2.1-cuda12.1-cudnn8-runtime

WORKDIR /app
COPY . /app

RUN pip install -r requirements.txt

CMD python3 run_inference.py

Ejecuta el comando | pip install | para instalar las dependencias de Python listadas en el
archivo | requirements.txt . Esto asegura que todas las librerías necesarias estén
disponibles en el contenedor, permitiendo que el script de Python se ejecute correctamente.
5. CMD python3 run_inference.py :

Define el comando por defecto que se ejecutará cuando el contenedor Docker sea
iniciado. En este caso, ejecutará el script | run_inference.py | utilizando Python 3. Este
script probablemente contiene el código para realizar la inferencia utilizando el modelo de PyTorch configurado.

fasterrcnn_resnet50_fpn.pth fasterrcnn_resnet50_fpn.pth

Contiene el modelo de detección de objetos pre-entrenado en un conjunto de datos de imágenes base. El modelo de detección de objetos se basa en FasterRCNN con ResNet50 como red base.

model_epoch_9.pth model_epoch_9.pth

Contiene el modelo de detección de objetos adaptado y afinado con un conjunto de datos de imágenes de maquinaria en obras de construcción, para cumplir los requisitos específicos del proyecto.

requirements.txt requirements.txt

Contiene las dependencias del sistema necesarias para ejecutar el modelo de detección de objetos. Se instalan automáticamente al construir la imagen de Docker.

run_inference.py run_inference.py

Es el script principal que se encarga de realizar las inferencias sobre las imágenes de maquinaria en obras de construcción. El script carga el modelo de detección de objetos, procesa las imágenes de entrada y genera las predicciones de los objetos detectados.

token.pickle token.pickle

Contiene las credenciales de acceso a la API de Google Drive. El token.pickle se utiliza para autenticar el sistema y acceder a las imágenes de maquinaria en obras de construcción almacenadas en Google Drive.

Volver al inicio

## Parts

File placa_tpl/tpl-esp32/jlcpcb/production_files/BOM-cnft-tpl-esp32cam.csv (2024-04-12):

Comment | Designator | Footprint | LCSC
SW_Push | SW1 | SKRKAEE020 | C115357
TPL5110 | U1 | TSOT-23-6 | C125830
200k | RV1 | Potentiometer_Bourns_TC33X_Vertical | C128551
Conn_01x02 | J3 | JST_PH_B2B-PH-SM4-TB_1x02-1MP_P2.00mm_Vertical | C160352
1k | R2 | R_0805_2012Metric | C25623
1M | R1 | R_0805_2012Metric | C26115
1uF | C1 | C_0805_2012Metric | C28323
Conn_01x08 | J1,J2 | PinSocket_1x08_P2.54mm_Vertical | C2897371
LED | D1 | LED_0603_1608Metric | C434423
47uF | C2 | CP_Elec_5x5.4 | C4747957
Conn_01x03 | J4,J5 | PinHeader_1x03_P2.54mm_Vertical | C492411
DMG3415 | U2 | SOT-23 | C96616

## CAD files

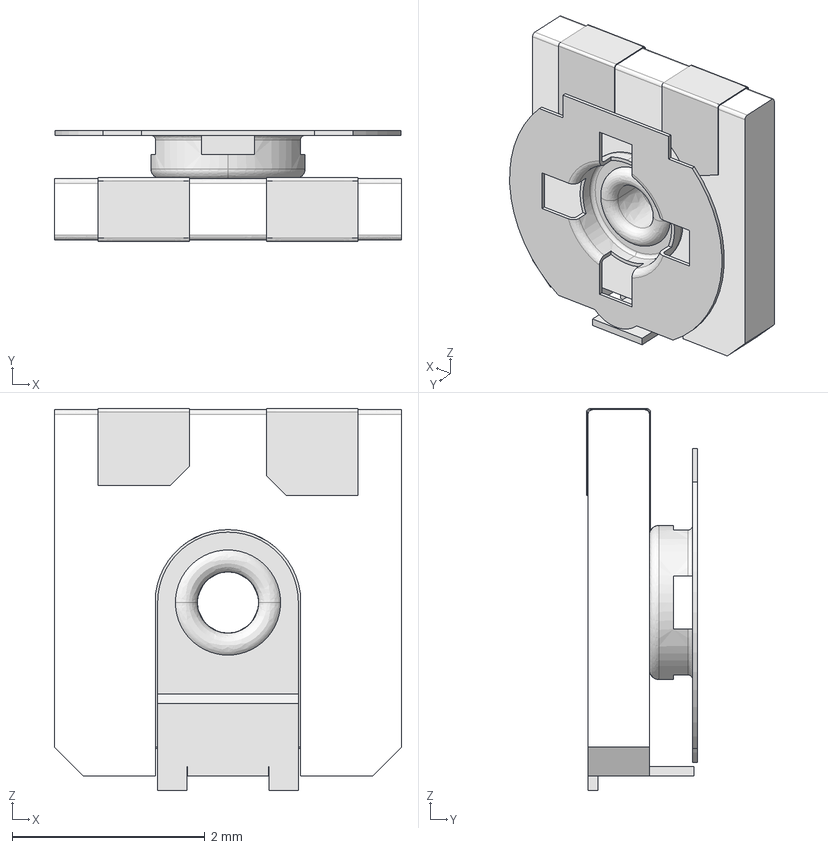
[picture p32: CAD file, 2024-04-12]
placa_tpl/tpl-esp32/3dparts/TC-33X-1_ASMTC33.step
3.60 x 1.15 x 3.96 mm

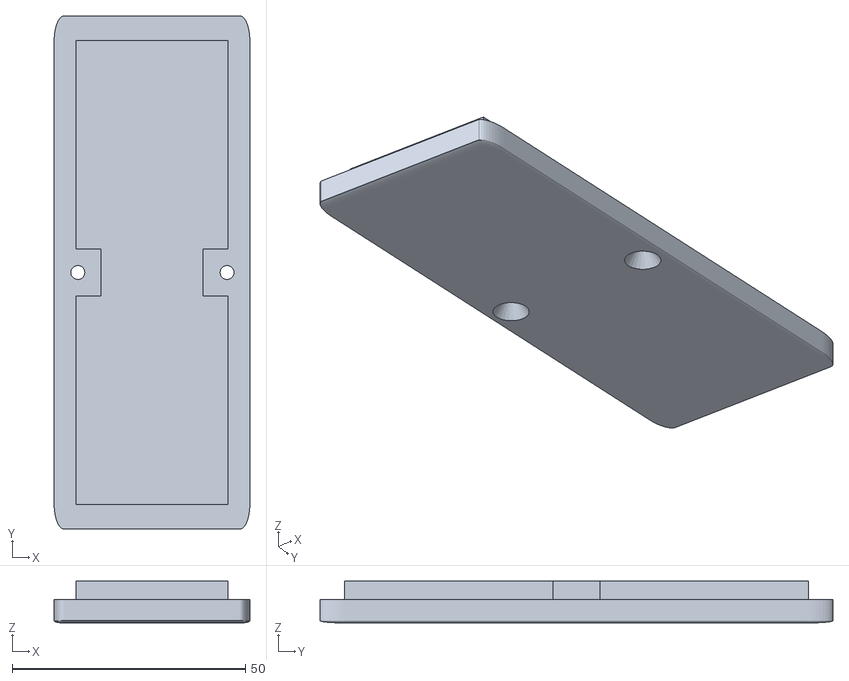
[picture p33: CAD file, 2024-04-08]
Design/Caja_Camara_P2.stl
42.0 x 110.0 x 9.00

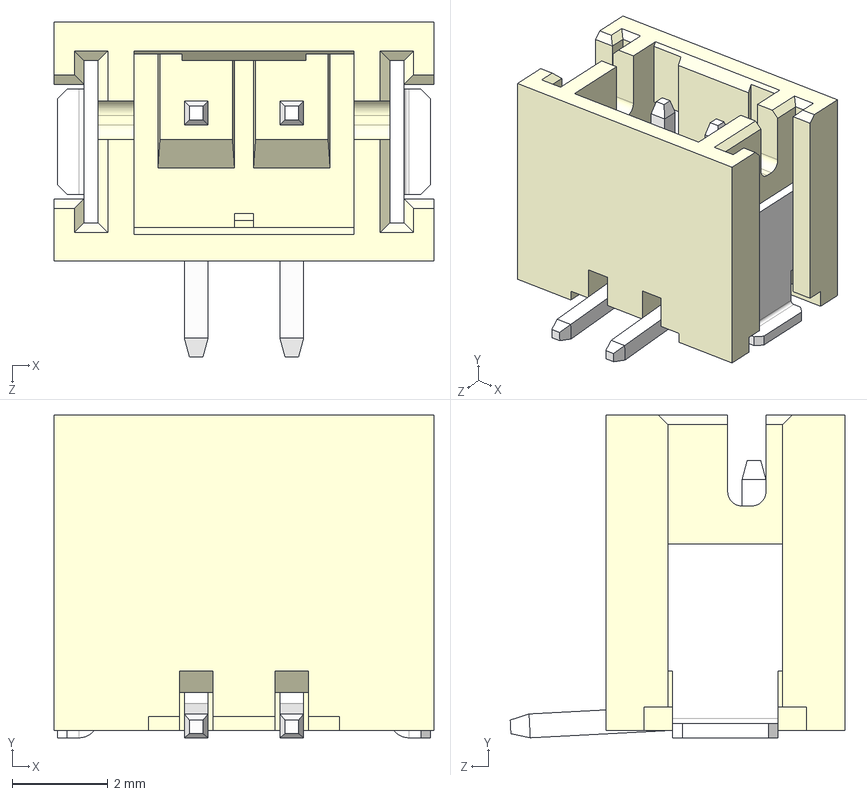
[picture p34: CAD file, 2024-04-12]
placa_tpl/tpl-esp32/3dparts/B2B-PH-SM4-TB.step
7.95 x 6.75 x 7.00 mm

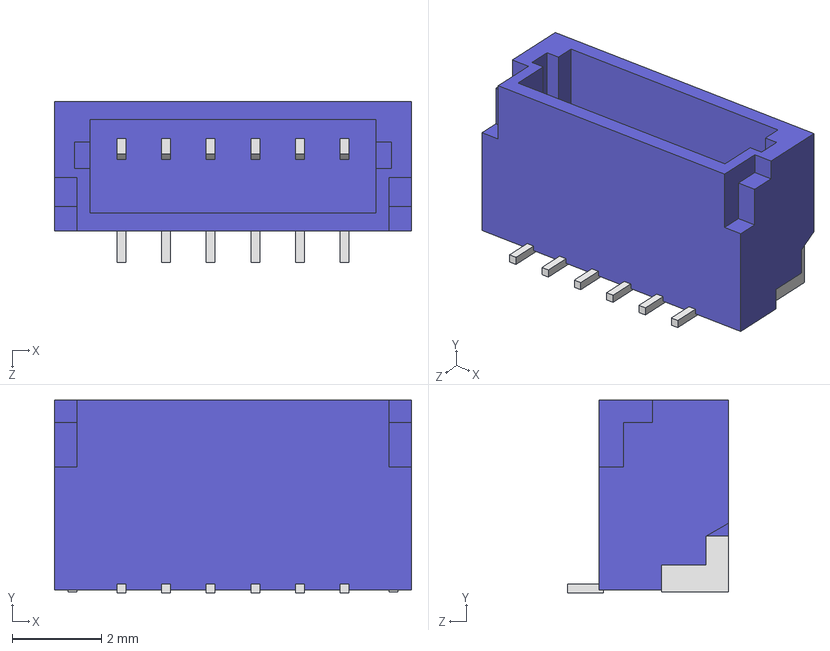
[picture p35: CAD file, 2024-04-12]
placa_tpl/tpl-esp32/3dparts/jst-sh-smd-connectors-1.snapshot.4/BMxxB-SRSR-TB/BM06B-SRSS-TB.STEP
8.00 x 4.32 x 3.60 mm

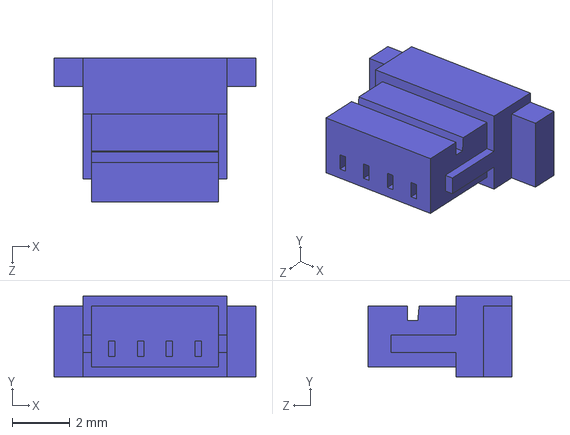
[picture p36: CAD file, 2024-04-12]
placa_tpl/tpl-esp32/3dparts/jst-sh-smd-connectors-1.snapshot.4/SHR-xxV-S-B/SHR-04V-S-B.STEP
7.00 x 2.80 x 5.00 mm

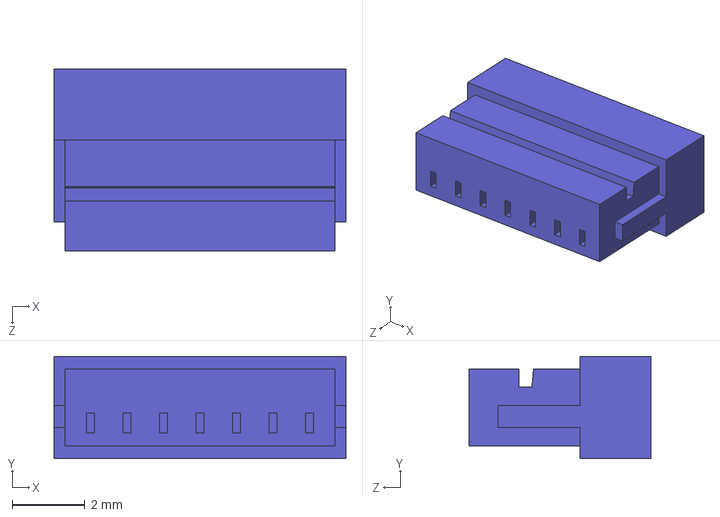
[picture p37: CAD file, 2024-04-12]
placa_tpl/tpl-esp32/3dparts/jst-sh-smd-connectors-1.snapshot.4/SHR-xxV-S/SHR-07V-S.STEP
8.00 x 2.80 x 5.00 mm

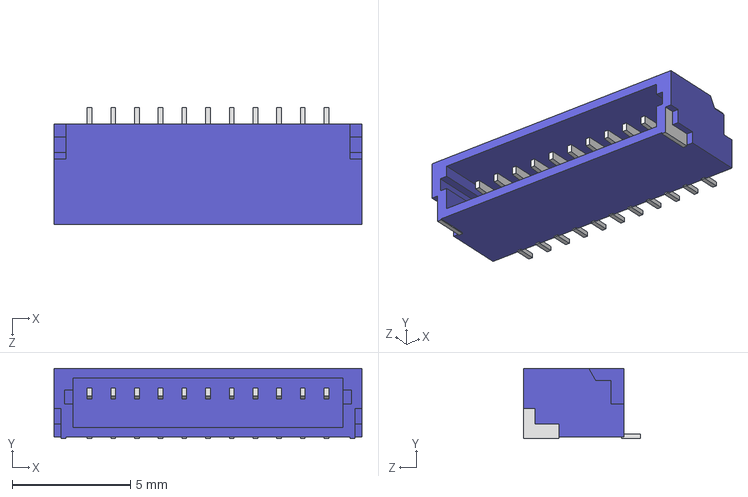
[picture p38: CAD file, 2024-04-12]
placa_tpl/tpl-esp32/3dparts/jst-sh-smd-connectors-1.snapshot.4/SMxxB-SRSS-TB/SM11B-SRSS-TB.STEP
13.0 x 2.96 x 4.95 mm

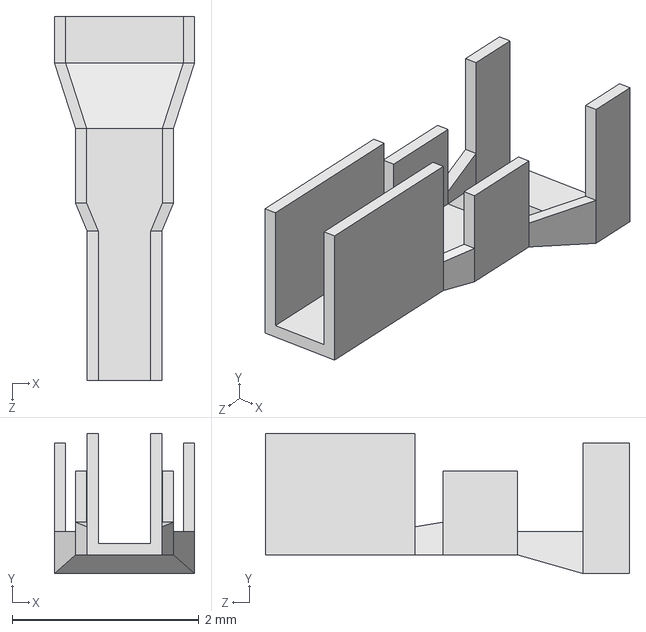
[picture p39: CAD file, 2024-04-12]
placa_tpl/tpl-esp32/3dparts/jst-sh-smd-connectors-1.snapshot.4/SSH-003T-P0.2-H/SSH-003T-P0.2-H.STEP
1.50 x 1.50 x 3.90 mm

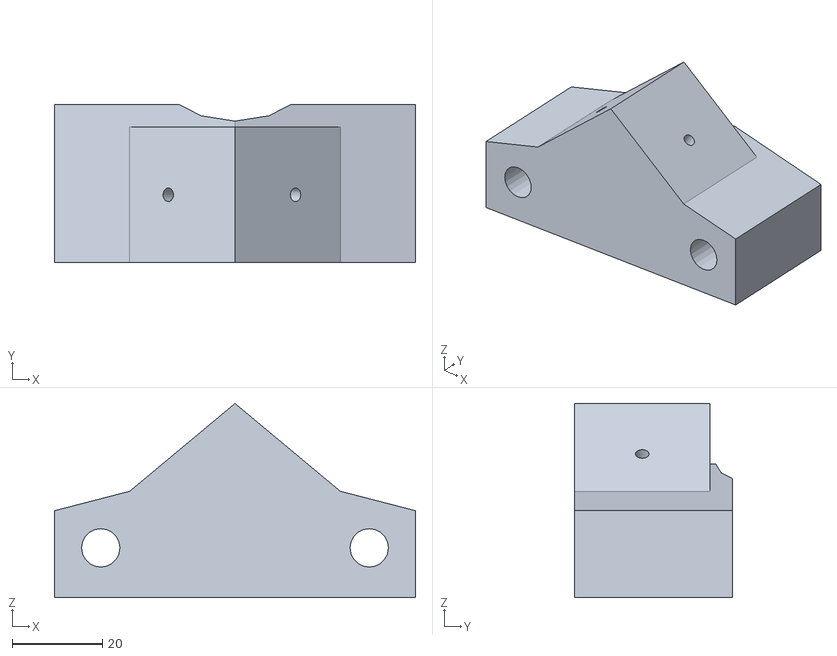
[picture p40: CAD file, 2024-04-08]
Design/Anclaje_Techo.stl
80.0 x 35.0 x 43.0

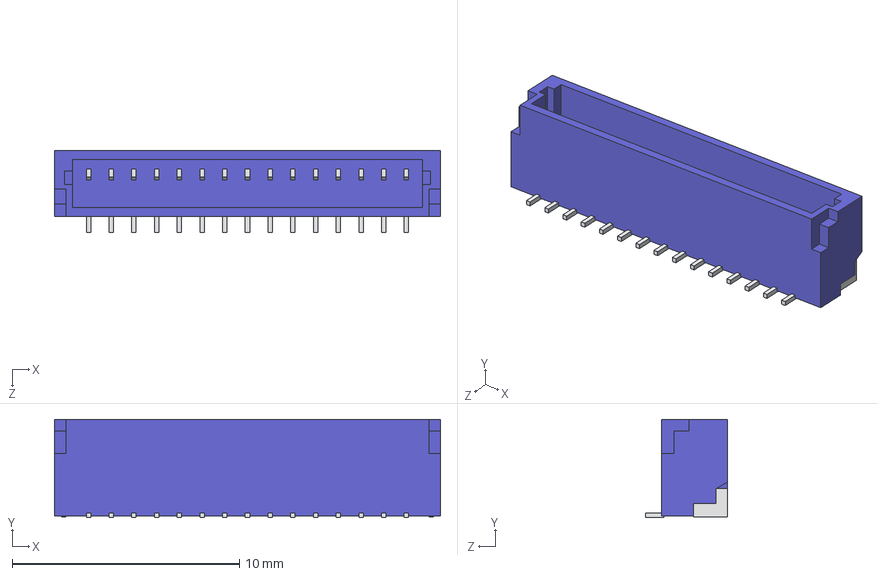
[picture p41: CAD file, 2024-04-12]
placa_tpl/tpl-esp32/3dparts/jst-sh-smd-connectors-1.snapshot.4/BMxxB-SRSR-TB/BM15B-SRSS-TB.STEP
17.0 x 4.32 x 3.60 mm

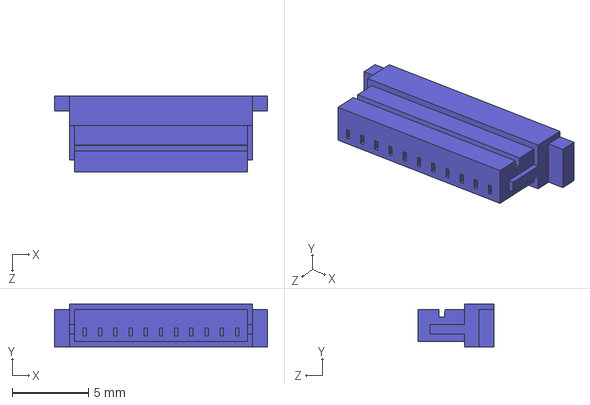
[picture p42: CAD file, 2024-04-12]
placa_tpl/tpl-esp32/3dparts/jst-sh-smd-connectors-1.snapshot.4/SHR-xxV-S-B/SHR-11V-S-B.STEP
14.0 x 2.80 x 5.00 mm

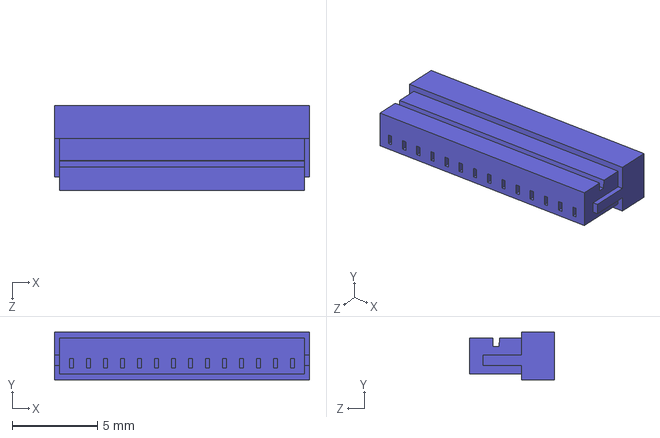
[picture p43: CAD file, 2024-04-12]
placa_tpl/tpl-esp32/3dparts/jst-sh-smd-connectors-1.snapshot.4/SHR-xxV-S/SHR-14V-S.STEP
15.0 x 2.80 x 5.00 mm

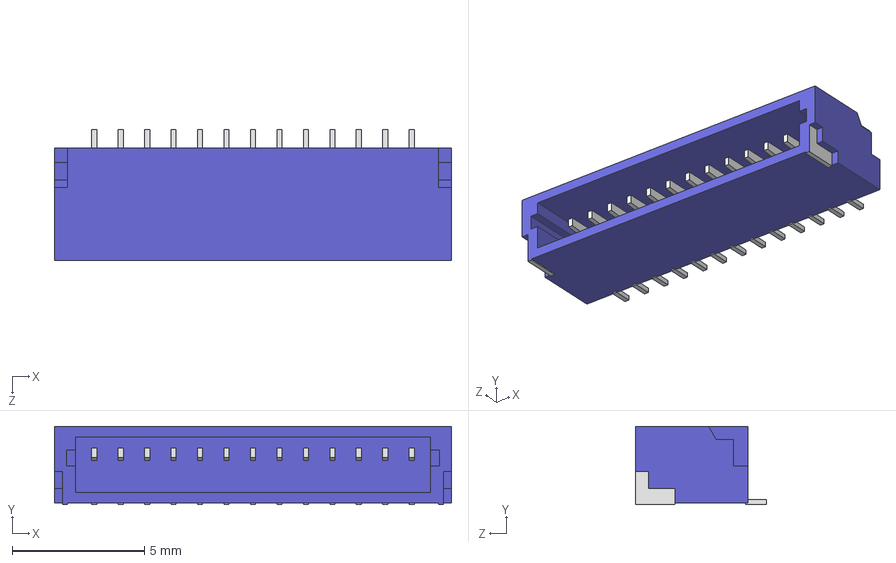
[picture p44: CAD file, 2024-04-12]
placa_tpl/tpl-esp32/3dparts/jst-sh-smd-connectors-1.snapshot.4/SMxxB-SRSS-TB/SM13B-SRSS-TB.STEP
15.0 x 2.96 x 4.95 mm

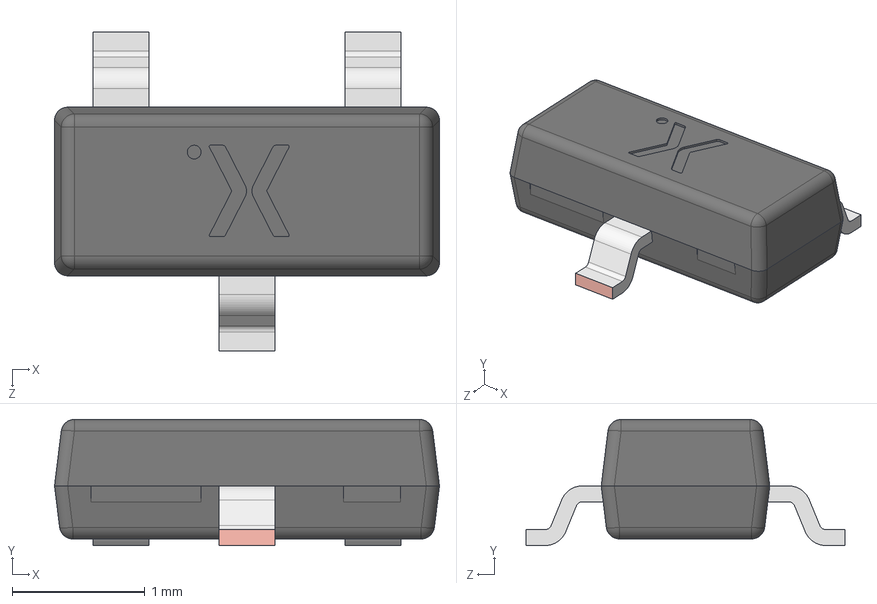
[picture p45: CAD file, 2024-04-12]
placa_tpl/tpl-esp32/3dparts/SOT23.step
2.90 x 0.95 x 2.40 mm
SOT23 lower body
SOT23 Lead x 3
SOT23 Upper body

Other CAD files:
Design/Caja_Camara_P1.stl
placa_tpl/tpl-esp32/3dparts/jst-sh-smd-connectors-1.snapshot.4/BMxxB-SRSR-TB/BM14B-SRSS-TB.STEP
placa_tpl/tpl-esp32/3dparts/jst-sh-smd-connectors-1.snapshot.4/SHR-xxV-S-B/SHR-20V-S-B.STEP
placa_tpl/tpl-esp32/3dparts/jst-sh-smd-connectors-1.snapshot.4/SHR-xxV-S/SHR-06V-S.STEP
Design/Union_Camara_Poste.stl
Design/Visor_Camara.stl
placa_tpl/tpl-esp32/3dparts/TC-33X-2.stp
placa_tpl/tpl-esp32/3dparts/jst-sh-smd-connectors-1.snapshot.4/BMxxB-SRSR-TB/BM02B-SRSS-TB.STEP
placa_tpl/tpl-esp32/3dparts/jst-sh-smd-connectors-1.snapshot.4/BMxxB-SRSR-TB/BM03B-SRSS-TB.STEP
placa_tpl/tpl-esp32/3dparts/jst-sh-smd-connectors-1.snapshot.4/BMxxB-SRSR-TB/BM04B-SRSS-TB.STEP
placa_tpl/tpl-esp32/3dparts/jst-sh-smd-connectors-1.snapshot.4/BMxxB-SRSR-TB/BM05B-SRSS-TB.STEP
placa_tpl/tpl-esp32/3dparts/jst-sh-smd-connectors-1.snapshot.4/BMxxB-SRSR-TB/BM07B-SRSS-TB.STEP
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

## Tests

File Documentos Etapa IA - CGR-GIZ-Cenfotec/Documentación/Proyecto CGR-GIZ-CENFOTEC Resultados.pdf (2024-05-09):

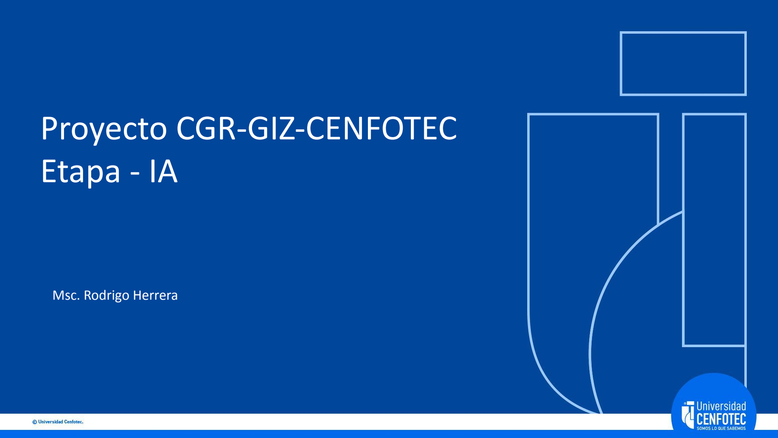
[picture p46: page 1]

## Proyecto CGR-GIZ-CENFOTEC Etapa - IA

Msc. Rodrigo Herrera

## CGR-GIZ-CENFOTEC

Objetivo

- Explicación de etapa de Inteligencia Artificial Aplicada en detección de Objetos para monitoreo de las construcciones

Agenda

- Imágenes
- Proceso de Etiquetado
- Proceso de Entrenamiento del modelo
- Resultados del modelo
- Arquitectura de Implementación
- Resultados de la arquitectura
- Explicación del Proceso API

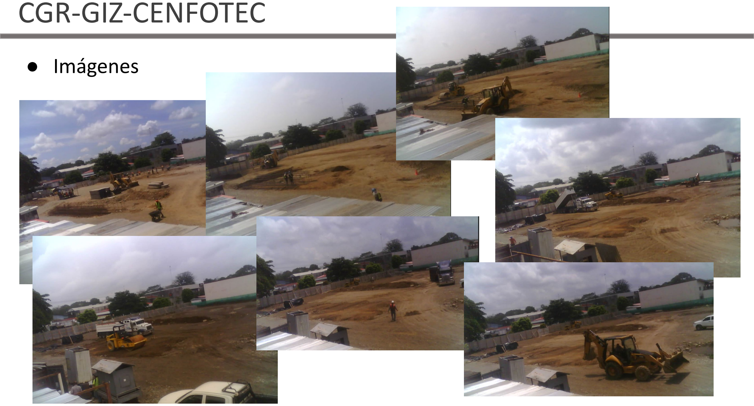
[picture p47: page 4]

- Imágenes

- Proceso de Etiquetado

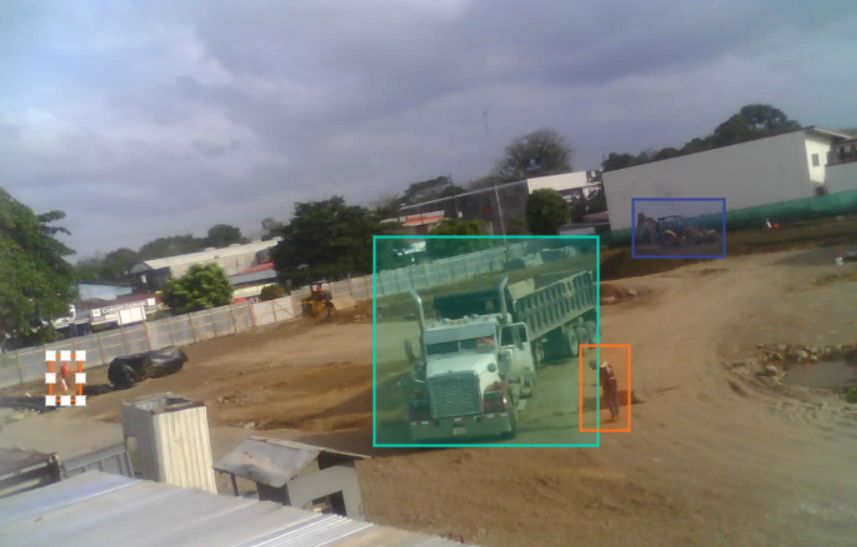
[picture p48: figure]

- Se etiquetan un total de
2,121 imágenes
- Se obtiene la siguiente
cantidad de etiquetas por
clase
- 751 Aplanadora
- 1,490 Persona
- 535 Tractor
- 445 Vagoneta
- 25 Mezcladora

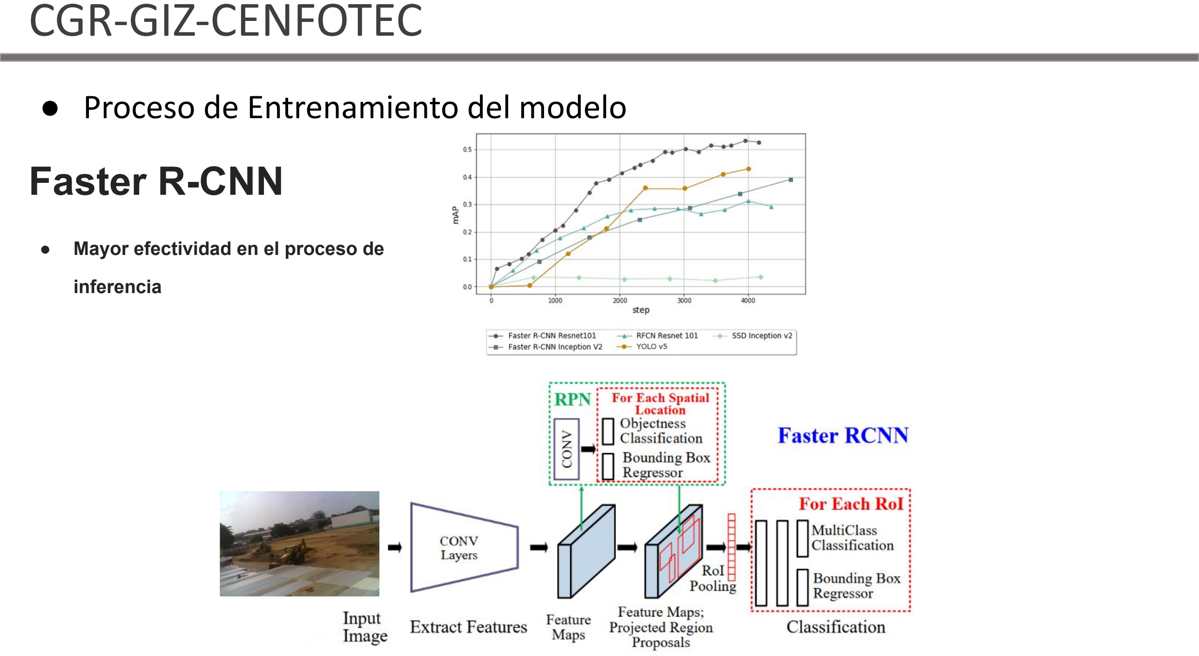
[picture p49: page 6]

- Proceso de Entrenamiento del modelo

Faster R-CNN

- Mayor efectividad en el proceso de

inferencia

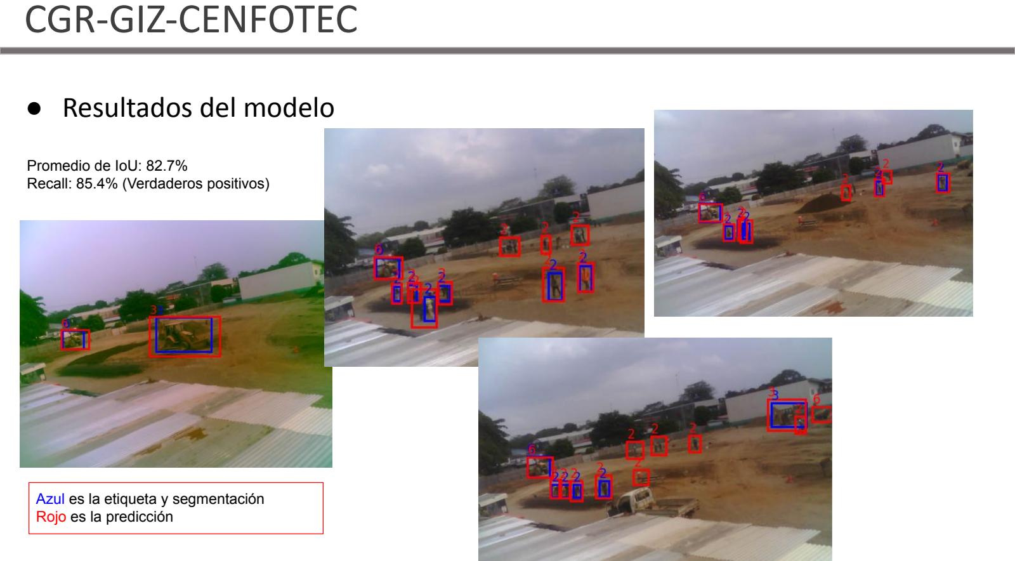
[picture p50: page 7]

- Resultados del modelo

Promedio de IoU: 82.7%
Recall: 85.4% (Verdaderos positivos)

Azul es la etiqueta y segmentación Rojo es la predicción

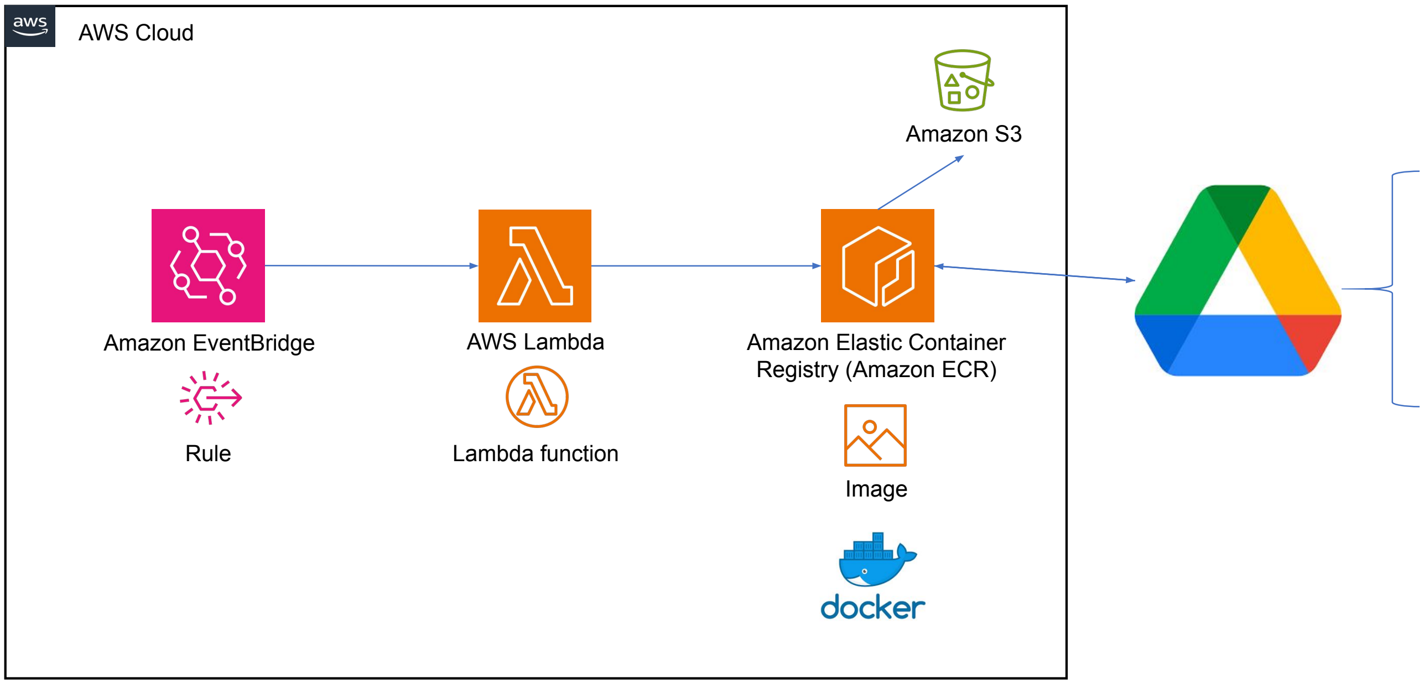
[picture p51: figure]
AWS Cloud; AWS Lambda; Lambda function; Amazon EventBridge; Rule; Amazon Elastic Container Registry (Amazon ECR); Image; Amazon S3

Folder Diario

Archivos

- Arquitectura de Implementación

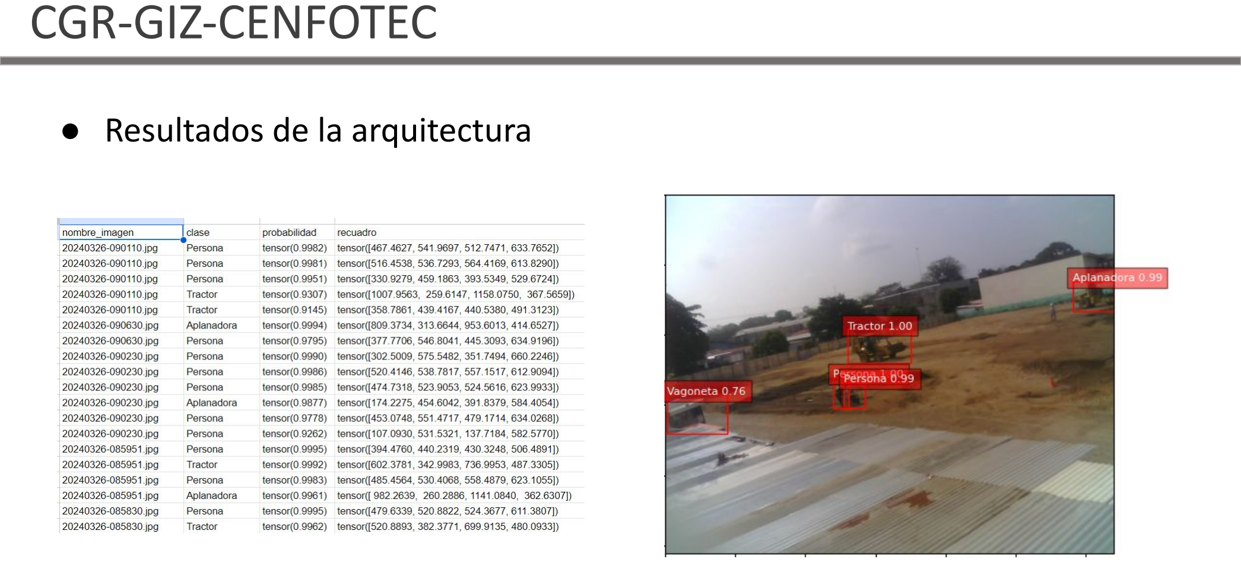
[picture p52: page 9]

- Resultados de la arquitectura

- Explicación del Proceso API

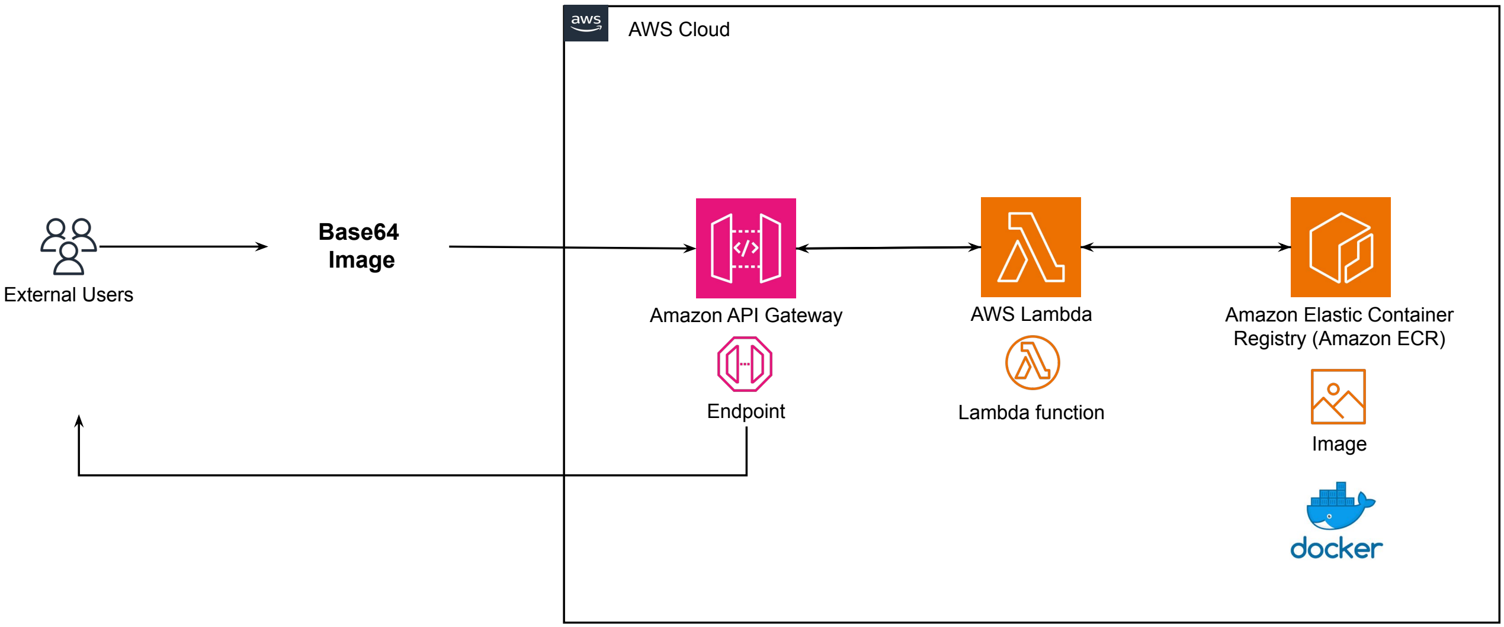
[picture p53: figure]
AWS Cloud; Amazon API Gateway; Endpoint; Amazon Elastic Container Registry (Amazon ECR); Image; AWS Lambda; Lambda function; External Users; Base64 Image

## Proyecto CGR-GIZ-CENFOTEC Etapa - IA

Msc. Rodrigo Herrera

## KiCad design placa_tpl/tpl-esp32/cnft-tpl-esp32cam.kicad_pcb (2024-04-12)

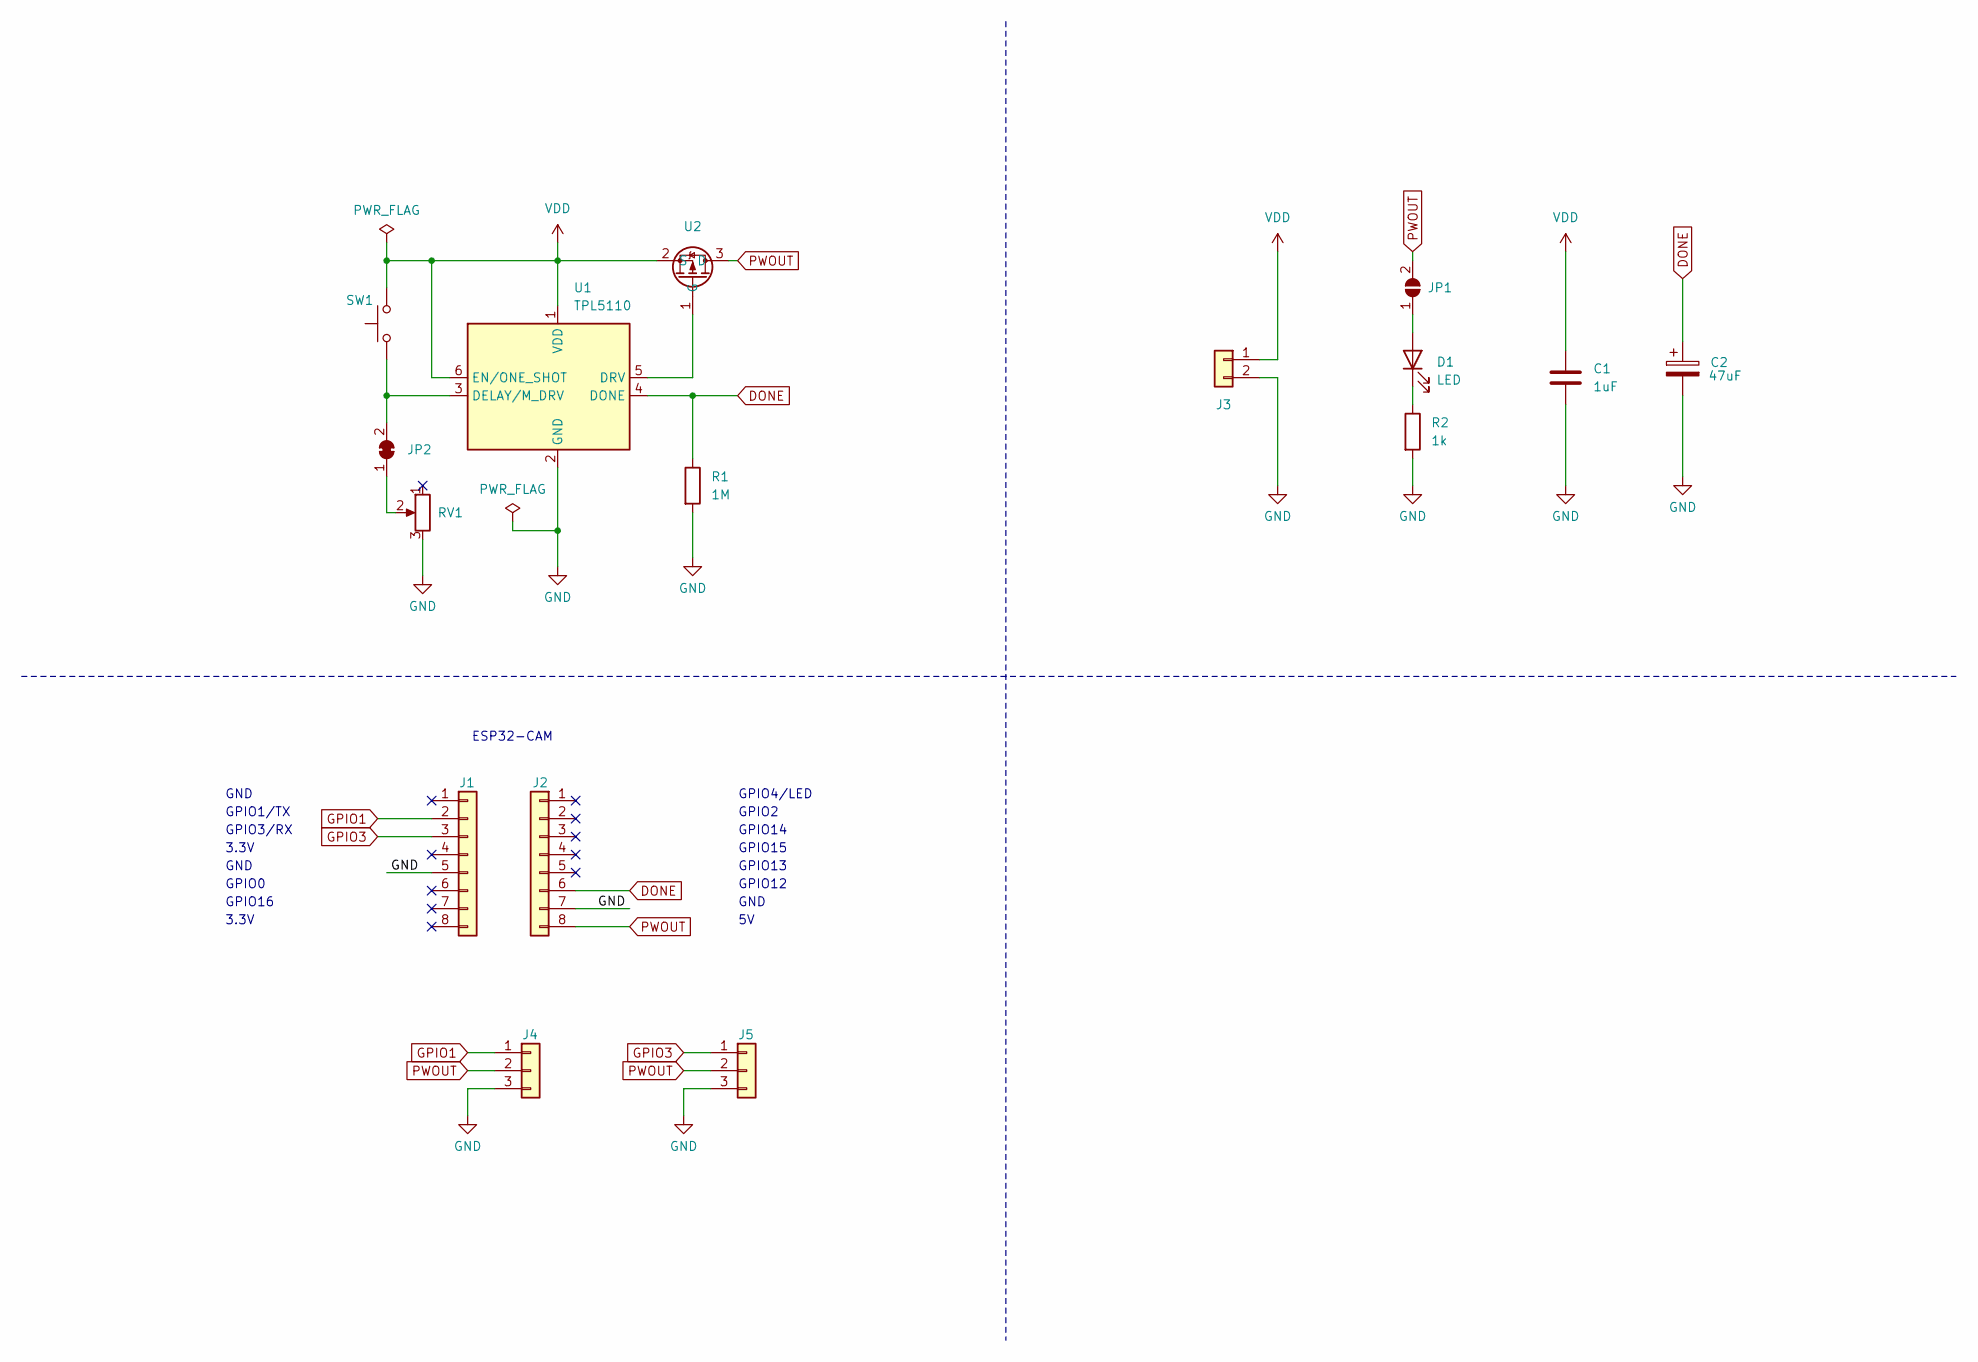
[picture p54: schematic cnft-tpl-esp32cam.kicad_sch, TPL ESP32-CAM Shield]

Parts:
C1: 1uF; C_0805_2012Metric
C2: 47uF; CP_Elec_5x5.4
D1: LED; LED_0603_1608Metric
J1, J2: Conn_01x08; PinSocket_1x08_P2.54mm_Vertical
J3: Conn_01x02; JST_PH_B2B-PH-SM4-TB_1x02-1MP_P2.00mm_Vertical
J4, J5: Conn_01x03; PinHeader_1x03_P2.54mm_Vertical
JP1: SolderJumper_2_Open; SolderJumper-2_P1.3mm_Open_RoundedPad1.0x1.5mm
JP2: SolderJumper_2_Bridged; SolderJumper-2_P1.3mm_Bridged_RoundedPad1.0x1.5mm
R1: 1M; R_0805_2012Metric
R2: 1k; R_0805_2012Metric
RV1: 200k; Potentiometer_Bourns_TC33X_Vertical
SW1: SW_Push; SKRKAEE020
U1: TPL5110; TSOT-23-6
U2: DMG3415; SOT-23

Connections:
DONE: C2.1, J2.6, R1.1, U1.4 (DONE)
GND: C1.2, C2.2, J1.5, J2.7, J3.2, J4.3, J5.3, R1.2, R2.2, RV1.3, U1.2 (GND)
GPIO1: J1.2, J4.1
GPIO3: J1.3, J5.1
unnamed: D1.2 (A), JP1.1 (A)
unnamed: D1.1 (K), R2.1
unnamed: JP2.1 (A), RV1.2
unnamed: JP2.2 (B), SW1.1, U1.3 (DELAY/M_DRV)
unnamed: U1.5 (DRV), U2.1 (G)
PWOUT: J2.8, J4.2, J5.2, JP1.2 (B), U2.3 (D)
VDD: C1.1, J3.1, SW1.2, U1.1 (VDD), U1.6 (EN/ONE_SHOT), U2.2 (S)

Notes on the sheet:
GND
GPIO13
GPIO12
GPIO0
GPIO4/LED
GPIO15
GPIO16
3.3V
GPIO2
ESP32-CAM
GPIO3/RX
GPIO14
GPIO1/TX

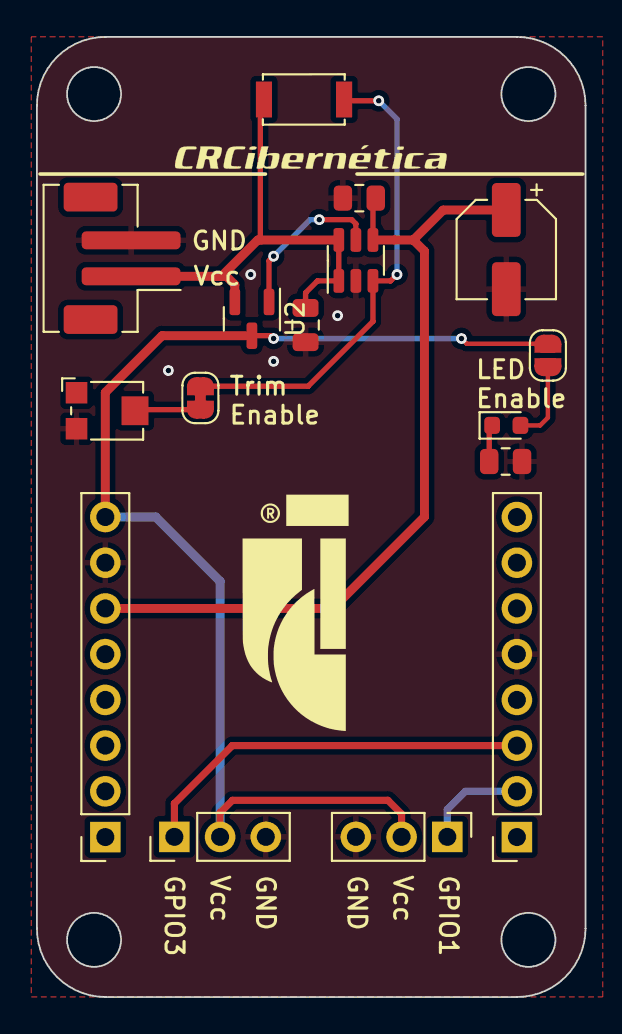
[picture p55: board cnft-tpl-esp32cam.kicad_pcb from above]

Board: 2 copper layers, 30.5 x 53.3 mm, 16 parts (0 on the bottom side), 11 nets.

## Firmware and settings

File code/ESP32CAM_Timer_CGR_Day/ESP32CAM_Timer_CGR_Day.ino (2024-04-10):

// Adadptado por Tomás de Camino
// Universidad Cenfotec

#include <WiFi.h>
#include <WiFiClientSecure.h>
#include "soc/soc.h"
#include "soc/rtc_cntl_reg.h"
#include "Base64.h"
#include "time.h"

#include "esp_camera.h"

//******* Datos de Red ******
//MIFI
const char* ssid = "your_SSID";           // El SSID de tu red
const char* password = "your_password";  // Tu contraseña de red


// ***************************

//Script para conectar al Google Drive
const char* myDomain = "script.google.com";
String myScript = "/macros/";    //Replace with your own url

String myFilename = "filename=ESP32-CAM.jpg";
String mimeType = "&mimetype=image/jpeg";
String myImage = "&data=";
int waitingTime = 10000;

// Espera 30 segundos a la respuesta de google.

//para tomar la hora del día
const char* ntpServer = "pool.ntp.org";
const long  gmtOffset_sec = -25200;  // Ajusta esto según tu zona horaria, en segundos (-7 horas)
const int   daylightOffset_sec = 3600; // Ajusta esto si tu zona horaria tiene horario de verano

//Datos de Cámara
#define CAMERA_MODEL_AI_THINKER
#define PWDN_GPIO_NUM 32
#define RESET_GPIO_NUM -1
#define XCLK_GPIO_NUM 0
#define SIOD_GPIO_NUM 26
#define SIOC_GPIO_NUM 27

#define Y9_GPIO_NUM 35
#define Y8_GPIO_NUM 34
#define Y7_GPIO_NUM 39
#define Y6_GPIO_NUM 36
#define Y5_GPIO_NUM 21
#define Y4_GPIO_NUM 19
#define Y3_GPIO_NUM 18
#define Y2_GPIO_NUM 5
#define VSYNC_GPIO_NUM 25
#define HREF_GPIO_NUM 23
#define PCLK_GPIO_NUM 22

#define MAX_TRIES 50

const int donepin = 12;  //12 en placas de CENFOTEC , 2 en prototipo
int tries = 0; //intentos de WiFi

void setup() {
  pinMode(donepin, OUTPUT);
  digitalWrite(donepin, LOW);

  WiFi.mode(WIFI_STA);

  WiFi.begin(ssid, password);


  while ((WiFi.status() != WL_CONNECTED) && (tries < MAX_TRIES)) {
    delay(500);
    tries++;
  }

  //si no pudo conectarse apaga de un vez
  if (tries >= MAX_TRIES) {
    // Enviar "Done" a timer
    digitalWrite(donepin, HIGH);
    delay(100);
  }

  // Inicializar SNTP
  configTime(gmtOffset_sec, daylightOffset_sec, ntpServer);


  int t = 0;
  struct tm timeinfo;
  while(!getLocalTime(&timeinfo)&&(t<20)){
    delay(50);
      t++;
  }

  // Comprobar si la hora actual está entre las 6 de la mañana y las 6 de la tarde
  //sino se desconecta
  if (timeinfo.tm_hour < 5 || timeinfo.tm_hour >= 18) {
      digitalWrite(donepin, HIGH);
      delay(100);
  }


  //Configuración de Cámara
  camera_config_t config;
  config.ledc_channel = LEDC_CHANNEL_0;
  config.ledc_timer = LEDC_TIMER_0;
  config.pin_d0 = Y2_GPIO_NUM;
  config.pin_d1 = Y3_GPIO_NUM;
  config.pin_d2 = Y4_GPIO_NUM;
  config.pin_d3 = Y5_GPIO_NUM;
  config.pin_d4 = Y6_GPIO_NUM;
  config.pin_d5 = Y7_GPIO_NUM;
  config.pin_d6 = Y8_GPIO_NUM;
  config.pin_d7 = Y9_GPIO_NUM;
  config.pin_xclk = XCLK_GPIO_NUM;
  config.pin_pclk = PCLK_GPIO_NUM;
  config.pin_vsync = VSYNC_GPIO_NUM;
  config.pin_href = HREF_GPIO_NUM;
  config.pin_sscb_sda = SIOD_GPIO_NUM;
  config.pin_sscb_scl = SIOC_GPIO_NUM;
  config.pin_pwdn = PWDN_GPIO_NUM;
  config.pin_reset = RESET_GPIO_NUM;
  config.xclk_freq_hz = 20000000;
  config.pixel_format = PIXFORMAT_JPEG;
  config.frame_size = FRAMESIZE_VGA;  // UXGA|SXGA|XGA|SVGA|VGA|CIF|QVGA|HQVGA|QQVGA
  config.jpeg_quality = 10;
  config.fb_count = 1;


  //Inicializa cámara
  esp_err_t err = esp_camera_init(&config);
  if (err != ESP_OK) {
    delay(300);
    ESP.restart();
  }

  //Cambia controles de cámara
  sensor_t* s = esp_camera_sensor_get();
  //s->set_gain_ctrl(s, 0); // 0 = disable , 1 = enable
  //s->set_exposure_ctrl(s, 0);  // auto-exposure 0 = disable , 1 = enable
  //s->set_agc_gain(s, 1); // set gain manually (0 - 30)
  //s->set_aec_value(s, 10);  // set exposure manually (0-1200)
  //s->set_ae_level(s, -2);


  //Other parameters
  //s->set_brightness(s, 0);     // -2 to 2
  s->set_contrast(s, 2);       // -2 to 2
  s->set_saturation(s, -2);     // -2 to 2
  //s->set_special_effect(s, 0); // 0 to 6 (0 - No Effect, 1 - Negative, 2 - Grayscale, 3 - Red Tint, 4 - Green Tint, 5 - Blue Tint, 6 - Sepia)
  //s->set_whitebal(s, 1);       // 0 = disable , 1 = enable
  //s->set_awb_gain(s, 1);       // 0 = disable , 1 = enable
  //s->set_wb_mode(s, 0);        // 0 to 4 - if awb_gain enabled (0 - Auto, 1 - Sunny, 2 - Cloudy, 3 - Office, 4 - Home)
  //s->set_exposure_ctrl(s, 1);  // 0 = disable , 1 = enable
  //s->set_aec2(s, 1);           // 0 = disable , 1 = enable
  //s->set_ae_level(s, -2);       // -2 to 2
  //s->set_aec_value(s, 0);    // 0 to 1200
  //s->set_gain_ctrl(s, 1);      // 0 = disable , 1 = enable
  //s->set_agc_gain(s, 0);       // 0 to 30
  //s->set_gainceiling(s, (gainceiling_t)0);  // 0 to 6
  //s->set_bpc(s, 0);            // 0 = disable , 1 = enable
  //s->set_wpc(s, 1);            // 0 = disable , 1 = enable
  //s->set_raw_gma(s, 1);        // 0 = disable , 1 = enable
  s->set_lenc(s, 0);           // 0 = disable , 1 = enable
  //s->set_hmirror(s, 0);        // 0 = disable , 1 = enable
  //s->set_vflip(s, 0);          // 0 = disable , 1 = enable
  //s->set_dcw(s, 1);            // 0 = disable , 1 = enable
  //s->set_colorbar(s, 0);       // 0 = disable , 1 = enable

  // Captura la imagen
  // if (WiFi.status() == WL_CONNECTED) {
  saveCapturedImage();
  delay(10);
  //}

  // Enviar "Done" a timer
  digitalWrite(donepin, HIGH);
  delay(100);
}


void loop() {
  //no corre
}

// ######################
void saveCapturedImage() {
  WiFiClientSecure client;
  client.setInsecure();

  if (client.connect(myDomain, 443)) {

    camera_fb_t* fb = NULL;
    fb = esp_camera_fb_get();
    if (!fb) {
      delay(1000);
      ESP.restart();
      return;
    }

    char* input = (char*)fb->buf;
    char output[base64_enc_len(3)];
    String imageFile = "";
    for (int i = 0; i < fb->len; i++) {
      base64_encode(output, (input++), 3);
      if (i % 3 == 0) imageFile += urlencode(String(output));
    }
    String Data = myFilename + mimeType + myImage;

    esp_camera_fb_return(fb);


    client.println("POST " + myScript + " HTTP/1.1");
    client.println("Host: " + String(myDomain));
    client.println("Content-Length: " + String(Data.length() + imageFile.length()));
    client.println("Content-Type: application/x-www-form-urlencoded");
    client.println();

    client.print(Data);
    int Index;
    for (Index = 0; Index < imageFile.length(); Index = Index + 1000) {
      client.print(imageFile.substring(Index, Index + 1000));
    }

    long int StartTime = millis();
    while (!client.available()) {
      delay(100);
      if ((StartTime + waitingTime) < millis()) {
        // Si no tiene respuesta, tal vez necesite un valor mayor de waitingTime
        break;
      }
    }
    //while (client.available()) {
    //Serial.print(char(client.read()));
    //}
  } else {
    //Serial.println("Connected to " + String(myDomain) + " failed.");
  }
  client.stop();
}

String urlencode(String str) {
  String encodedString = "";
  char c;
  char code0;
  char code1;
  char code2;
  for (int i = 0; i < str.length(); i++) {
    c = str.charAt(i);
    if (c == ' ') {
      encodedString += '+';
    } else if (isalnum(c)) {
      encodedString += c;
    } else {
      code1 = (c & 0xf) + '0';
      if ((c & 0xf) > 9) {
        code1 = (c & 0xf) - 10 + 'A';
      }
      c = (c >> 4) & 0xf;
      code0 = c + '0';
      if (c > 9) {
        code0 = c - 10 + 'A';
      }
      code2 = '\0';
      encodedString += '%';
      encodedString += code0;
      encodedString += code1;
      //encodedString+=code2;
    }
    yield();
  }
  return encodedString;
}

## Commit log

2023-10-25 Captura y carga de fotos con ESP32-CAM
    Agrega el código necesario para capturar fotos automáticamente cada minuto utilizando una cámara ESP32-CAM y cargarlas de inmediato a Google Drive. Esto permitirá la monitorización y grabación periód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
2023-10-25 Script Google Drive
    Permite la configuración de Google Drive para recibir las fotos enviadas desde la ESP32-CAM.
2023-10-31 esp32-cam deepsleep
2023-11-01 esp32-cam deep sleep
2024-04-08 Delete Design/Box_Camera_V1.stl
    Obsoleto
    [Box_Camera_V1.stl]
2024-04-08 Delete Design/Camera_Box_Full.stl
    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
    [Camera_Box_Full.stl]
2024-04-08 Delete Design/Camera_Box2_3.stl
    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
    [Camera_Box2_3.stl]
2024-04-08 Update README.md
    Actualización de archivos de impresión 3D, con versión final
2024-04-08 Update README.md
    Cambio de título
2024-04-10 Update README.md
    Descripción de código
2024-04-29 Add files via upload
    Presentaciones realizadas durante el proyecto
2024-05-03 Create prueba de lnaranjo
2024-05-03 Update README.md
    Agregado de instrucciones de Arduino IDE
2024-05-03 Update README.md
    Instrucciones de creación de acceso a google drive
